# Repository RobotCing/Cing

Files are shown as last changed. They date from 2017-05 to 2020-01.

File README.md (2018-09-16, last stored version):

| [**Úvod**](README.md) |[**Cing**](README-cing-sk.md)  |[**GalejeNextGen**](README-GNG-sk.md)|[**Kontakt**](README-kontakt.md)|[**English version**](README-en.md)|[**Arduino portable**](https://drive.google.com/file/d/1-qsKpOY3mSJC7BOQW4kqXe5UFbl79BuX/view?usp=sharing)|
|:---:|:---:|:---:|:---:|:---:|:---:|
|[Attiny 85](README-Attiny85.md)|[Attiny 84](README-Attiny84.md)|[Atmega 8](README-Atmega8.md)|[Attiny 13](README-Attiny13.md)|[Atmega 328](README-Atmega328.md)|[Atmega 32u4](README-Atmega32u4.md)|

## Úvod:
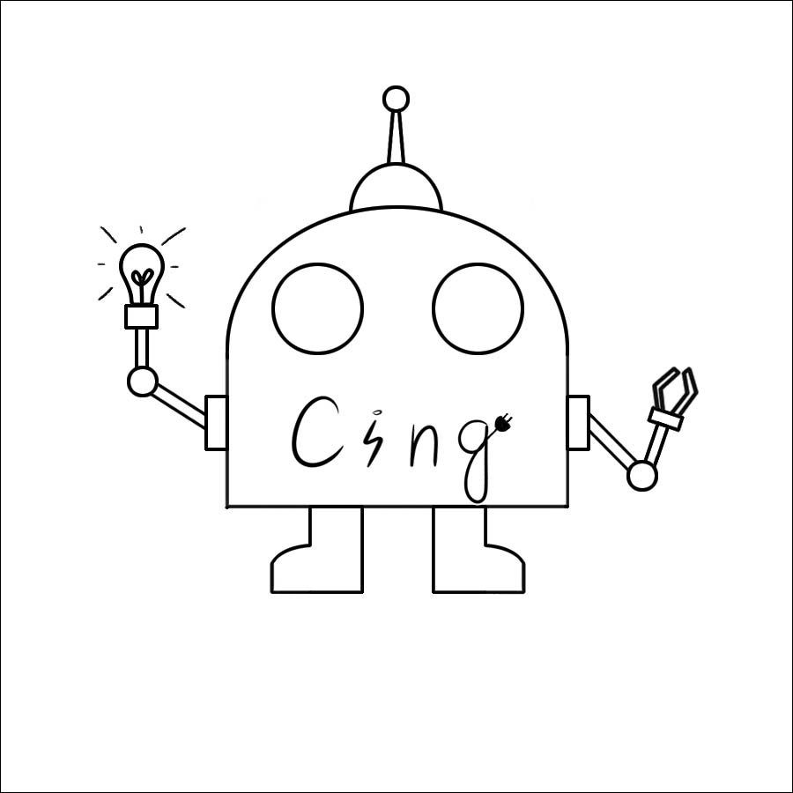
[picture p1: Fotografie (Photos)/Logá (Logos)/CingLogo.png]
Atmega 328 schematic


Každý pozná firmu [Lego](https://www.lego.com/en-us/). Vyrábajú najpopulárnejšie [Lego](https://www.lego.com/en-us/) stavebnice a sety. Vyrábajú <a href="https://www.lego.com/en-us/mindstorms">Lego NXT a Lego EV3</a> sety, ktoré sa jednoducho programujú a konštruujú, ale po naučení sa ich obrázkoveho jednoduchého programovacieho jazyka nemá užívaťeľ ďalšie možnosti ako programovať ich lego stavebnicu. Užívateľovi ostáva jediná možnosť - prejsť na inú platformu, napríklad [Arduino](https://www.arduino.cc/). 

[Arduino](https://www.arduino.cc/) je jedna z najlepších možností, nakoľko je lacnejšie ako akákoľvek iná platforma a taktiež je voľne dostupné. Ak sa užívateľ chce venovať [Arduinu](https://www.arduino.cc/), musí mať znalosti z elektroniky. Avšak tento fakt si mnoho ľudí uvedomí až keď si [Arduino](https://www.arduino.cc/) kúpi a vačšina z nich to vzdá. 

Preto sme vytvroli robota <a href="https://github.com/Galeje/Cing" target= "_blank">Cing</a> - je to multifunkčný a praktický robot pre všetky vekové kategórie od začiatočníkov až po expertov, nakoľko nie je potrebná žiadna znalosť z elektorniky či programovania. Pomocou nami vytvorených <a href="https://github.com/Galeje/Cing/tree/master/libraries" target= "_blank">knižníc</a>, ktoré umožňujü praktické a jednoduché využitie robota <a href="https://github.com/Galeje/Cing" target= "_blank">Cing</a> sa užívateľ naučí rýchlo, hravo a efektívne programovať.

Pre ešte ľahšie programovanie a učenie sa sme vytvorili príručky, ktoré obsahujú všetky programy a následne ich vysvetľujú. Aby užívateľ vedel, ako správne poskladať robota <a href="https://github.com/Galeje/Cing" target= "_blank">Cing</a>, použije opäť nami vytvorený manuál. Po naučení sa základných príkazov si môže vyskúšať cvičenia zo zbierky úloh na plátne s atrakciami.

Po zvládnutí základných aj pokročilých progamovacích príkazov môže používateľ použiť robota <a href="https://github.com/Galeje/Cing" target= "_blank">Cing</a> ako nástroj pre učenie sa elektroniky, nakoľko sa jednoducho dostane k schémam aj príručke, ako ho programovať bez použitia <a href="https://github.com/Galeje/Cing/tree/master/libraries" target= "_blank">knižníc</a>. To znamená, že užívateľ si môže vybrať, ako chce programovať <a href="https://github.com/Galeje/" target= "_blank">Cing-a</a>.

<!---Každú pozná firmu [Lego](https://www.lego.com/en-us/). Vyrábajú najpopulárnejšie [Lego](https://www.lego.com/en-us/) stavebnice a sety. Vyrábajú <a href="https://www.lego.com/en-us/mindstorms">Lego NXT and Lego EV3</a>sety ktoré sa jednoducho programujú a konštruujú, ale po naučení sa ich obrázkoveho jednoduchého programovacieho jazyka nemá užívaťeľ ďalšie možnosti ako programovat ich lego stavebnicu. Užívateľovi ostáva jediná možnosť - Prejisť na inú platformu napríklad [Arduino](https://www.arduino.cc/). [Arduino](https://www.arduino.cc/) je super možnosť nakoľko je Open Source, je lacnejšie, ale užívaťel musí rozumieť elektronike. Tento fakt si mnoho ľudí uvedomí až keď si [Arduino](https://www.arduino.cc/) kúpi a vačšina ľudí to vzdá.
<a href="https://github.com/Galeje/Cing" target= "_blank">Cing</a> rieši tento problém <a href="https://github.com/Galeje/Cing/tree/master/libraries" target= "_blank">knižnicami</a> ktoré umožňujú jednoduché programovanie <a href="https://github.com/Galeje/Cing" target= "_blank">Cing-a</a> v C programovaciom jazyku bez nutnosťi znalosti elektroniky. Taktiež sme vytvorili <a href="https://github.com/Galeje/Cing/blob/master/CINGtlac.pdf">príručky</a>, ktoré naučia užívateľa programovat <a href="https://github.com/Galeje/Cing" target= "_blank">Cing-a</a>.Po naučení sa základných aj pokročilých progamovacích príkazov môže používateľ použiť robota <a href="https://github.com/Galeje/Cing" target= "_blank">Cing</a> ako nástroj pre učenie sa elektroniky, nakoľko sa jednoducho dostane k schémam aj príručke ako ho programovať bez použitia <a href="https://github.com/Galeje/Cing/tree/master/libraries" target= "_blank">knižníc</a>. To znamená, že užívateľ si môže vybrať ako chce programovať <a href="https://github.com/Galeje/Cing" target= "_blank">Cing-a</a>.--->

## Package link
`https://raw.githubusercontent.com/RobotCing/Cing/master/Software/Packages/index/package_RobotCing_index.json`

Projekt používa <a href="https://github.com/MCUdude/MicroCore">MicroCore</a> a <a href="https://github.com/damellis">Damellis</a> <a href="https://github.com/damellis/attiny">ATtiny core</a>.

## Podporte nás:




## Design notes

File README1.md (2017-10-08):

|||||||
|---|---|---|---|---|---|
| [**Úvod**](README-sk.md) | [**Cing**](README-cing-sk.md)  |[**GalejeNextGen**](README-GNG-sk.md) |[**Kontakt**](README-kontakt.md)|[**English version**](README.md)|[**Arduino portable**](https://drive.google.com/file/d/0B4RmGq_2LqvyWHNMNzY1T0phVmM/view?usp=sharing)|

## Úvod:
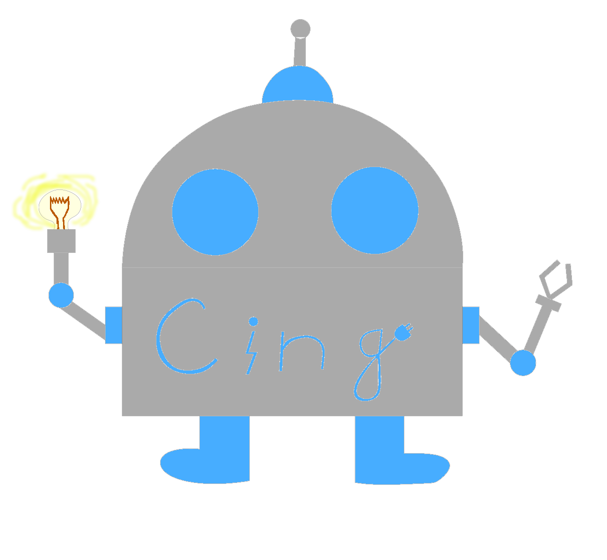
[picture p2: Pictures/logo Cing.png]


Každý pozná firmu [Lego](https://www.lego.com/en-us/). Vyrábajú najpopulárnejšie [Lego](https://www.lego.com/en-us/) stavebnice a sety. Vyrábajú <a href="https://www.lego.com/en-us/mindstorms">Lego NXT a Lego EV3</a> sety, ktoré sa jednoducho programujú a konštruujú, ale po naučení sa ich obrázkoveho jednoduchého programovacieho jazyka nemá užívaťeľ ďalšie možnosti ako programovať ich lego stavebnicu. Užívateľovi ostáva jediná možnosť - prejsť na inú platformu, napríklad [Arduino](https://www.arduino.cc/). 

[Arduino](https://www.arduino.cc/) je jedna z najlepších možností, nakoľko je lacnejšie ako akákoľvek iná platforma a taktiež je voľne dostupné. Ak sa užívateľ chce venovať [Arduinu](https://www.arduino.cc/), musí mať znalosti z elektroniky. Avšak tento fakt si mnoho ľudí uvedomí až keď si [Arduino](https://www.arduino.cc/) kúpi a vačšina z nich to vzdá. 

Preto sme vytvroli robota <a href="https://github.com/Galeje/Cing" target= "_blank">Cing</a> - je to multifunkčný a praktický robot pre všetky vekové kategórie od začiatočníkov až po expertov, nakoľko nie je potrebná žiadna znalosť z elektorniky či programovania. Pomocou nami vytvorených <a href="https://github.com/Galeje/Cing/tree/master/libraries" target= "_blank">knižníc</a>, ktoré umožňujü praktické a jednoduché využitie robota <a href="https://github.com/Galeje/Cing" target= "_blank">Cing</a> sa užívateľ naučí rýchlo, hravo a efektívne programovať.

Pre ešte ľahšie programovanie a učenie sa sme vytvorili príručky, ktoré obsahujú všetky programy a následne ich vysvetľujú. Aby užívateľ vedel, ako správne poskladať robota <a href="https://github.com/Galeje/Cing" target= "_blank">Cing</a>, použije opäť nami vytvorený manuál. Po naučení sa základných príkazov si môže vyskúšať cvičenia zo zbierky úloh na plátne s atrakciami.

Po zvládnutí základných aj pokročilých progamovacích príkazov môže používateľ použiť robota <a href="https://github.com/Galeje/Cing" target= "_blank">Cing</a> ako nástroj pre učenie sa elektroniky, nakoľko sa jednoducho dostane k schémam aj príručke, ako ho programovať bez použitia <a href="https://github.com/Galeje/Cing/tree/master/libraries" target= "_blank">knižníc</a>. To znamená, že užívateľ si môže vybrať, ako chce programovať <a href="https://github.com/Galeje/" target= "_blank">Cing-a</a>.

<!---Každú pozná firmu [Lego](https://www.lego.com/en-us/). Vyrábajú najpopulárnejšie [Lego](https://www.lego.com/en-us/) stavebnice a sety. Vyrábajú <a href="https://www.lego.com/en-us/mindstorms">Lego NXT and Lego EV3</a>sety ktoré sa jednoducho programujú a konštruujú, ale po naučení sa ich obrázkoveho jednoduchého programovacieho jazyka nemá užívaťeľ ďalšie možnosti ako programovat ich lego stavebnicu. Užívateľovi ostáva jediná možnosť - Prejisť na inú platformu napríklad [Arduino](https://www.arduino.cc/). [Arduino](https://www.arduino.cc/) je super možnosť nakoľko je Open Source, je lacnejšie, ale užívaťel musí rozumieť elektronike. Tento fakt si mnoho ľudí uvedomí až keď si [Arduino](https://www.arduino.cc/) kúpi a vačšina ľudí to vzdá.
<a href="https://github.com/Galeje/Cing" target= "_blank">Cing</a> rieši tento problém <a href="https://github.com/Galeje/Cing/tree/master/libraries" target= "_blank">knižnicami</a> ktoré umožňujú jednoduché programovanie <a href="https://github.com/Galeje/Cing" target= "_blank">Cing-a</a> v C programovaciom jazyku bez nutnosťi znalosti elektroniky. Taktiež sme vytvorili <a href="https://github.com/Galeje/Cing/blob/master/CINGtlac.pdf">príručky</a>, ktoré naučia užívateľa programovat <a href="https://github.com/Galeje/Cing" target= "_blank">Cing-a</a>.Po naučení sa základných aj pokročilých progamovacích príkazov môže používateľ použiť robota <a href="https://github.com/Galeje/Cing" target= "_blank">Cing</a> ako nástroj pre učenie sa elektroniky, nakoľko sa jednoducho dostane k schémam aj príručke ako ho programovať bez použitia <a href="https://github.com/Galeje/Cing/tree/master/libraries" target= "_blank">knižníc</a>. To znamená, že užívateľ si môže vybrať ako chce programovať <a href="https://github.com/Galeje/Cing" target= "_blank">Cing-a</a>.--->
## Prehľad:
Cing model
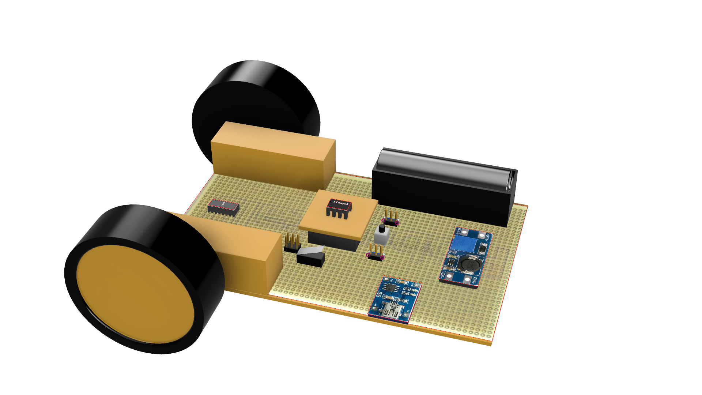
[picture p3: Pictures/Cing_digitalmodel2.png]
Cing model


<a href="https://goo.gl/kuoLt5" target="_blank">Stiahni Arduino Portable</a>

## Komponenty:
 - ### Procesory:
   - Attiny13 procesor
   - Attiny85 procesor
   - Attiny84 procesor
   - Atmega8 procesor
   - Atmega328 procesor
   - Atmega32u4 procesor(vo vývoji)
 - ### Senzory(Vstupy):
   - DS18B20 temperature sensor
   - Shine sensor
   - 2 x light sensor
   - ultasonic sensor
 - ### Výstupy:
   - L293D
   - Display128x32(vo vývoji)
 - ### Robot parts:
   - Základny robot
   - ICSP programmer
   - Li-Ion 18650 baterka
   - ICSP ASP programátor
 - ### Potrebné nástroje:
   - Počítač
   - Čierna páska(izolepa) pre vytvorenie čiar
   - Povrch pre čiaru
   - Prekážky

## Schémy:
### Schéma Atmega328 procesor
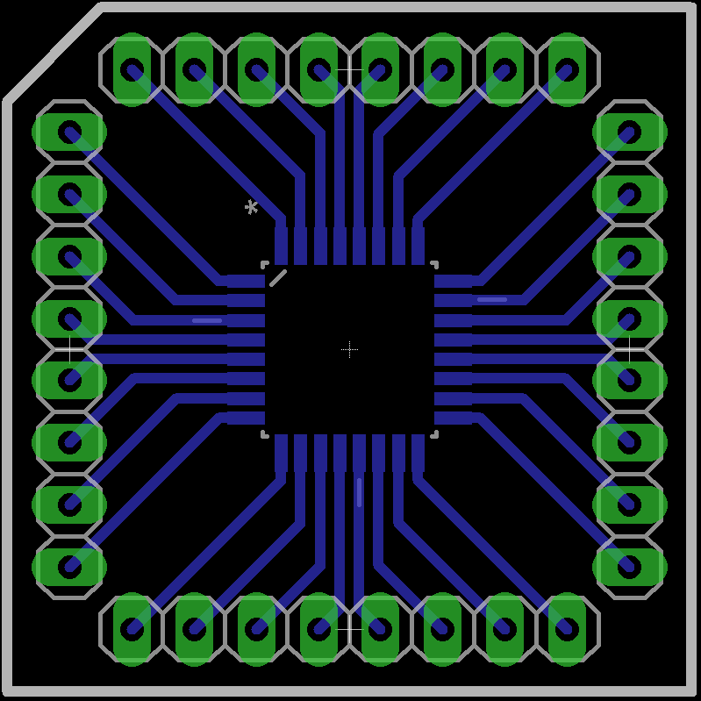
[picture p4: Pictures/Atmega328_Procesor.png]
Atmega 328 schematic

### Schéma Atmega8 procesor
<a href="https://github.com/Galeje/Cing/tree/master/Schematic">Atmega 8 schematic</a>
### Schéma Attiny85 procesor
<a href="https://github.com/Galeje/Cing/tree/master/Schematic">Attiny 85 schematic</a>
### Schéma Cing robot
<a href="https://github.com/Galeje/Cing/tree/master/Schematic">Cing schematic</a>

## Fotky:
### Poskladaný robot:
Cing assembled

## Podporte nás:




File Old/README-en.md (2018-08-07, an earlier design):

| [**Introduction**](README-en.md) |[**Cing**](README-cing.md)  |[**GalejeNextGen**](README-GNG.md)|[**Contact**](README-contact.md)|[**Slovak version**](README.md)|[**Arduino portable**](https://goo.gl/Sfmrn4)|
|:---:|:---:|:---:|:---:|:---:|:---:|
|[Attiny 85](README-Attiny85-en.md)|[Attiny 84](README-Attiny84-en.md)|[Atmega 8](README-Atmega8-en.md)|[Attiny 13](README-Attiny13-en.md)|[Atmega 328](README-Atmega328-en.md)|[Atmega 32u4](README-Atmega32u4-en.md)|

## Introduction:


Everybody knows [Lego](https://www.lego.com/en-us/) as an campany. They are making most popular [Lego](https://www.lego.com/en-us/) sets and robots ever. They have <a href="https://www.lego.com/en-us/mindstorms">Lego NXT and Lego EV3</a> robot sets which are easy to program and build, but after you have learned how to program them with [Lego](https://www.lego.com/en-us/) software there isn't any other programing language. So  if you want to learn some other language you have to get something else for example [Arduino](https://www.arduino.cc/).

[Arduino](https://www.arduino.cc/) is great platform because it is an open source, cheaper than [Lego](https://www.lego.com/en-us/) and you aren't that limited. But when you get arduino you will sooner or later realise, that you have to know how electronics works. And that's the point where most of people will give up.

<a href="https://github.com/Galeje/Cing" target= "_blank">Cing</a> solves this problem because it has a <a href="https://github.com/Galeje/ing/tree/master/libraries" target= "_blank">libraries</a> which allow users to easely program <a href="https://github.com/Galeje/Cing" target= "_blank">Cing</a> in C language without electronic knowleadge. We also created pdf <a href="https://github.com/Galeje/Cing/blob/master/CINGtlac.pdf">guide</a>  which teaches you the basics of programing <a href="https://github.com/Galeje/Cing" target= "_blank">Cing</a> robot. 

After learning the basics of programing with <a href="https://github.com/Galeje/ing/tree/master/libraries" target= "_blank">libraries</a> they can use <a href="https://github.com/Galeje/Cing" target= "_blank">Cing</a> robot as learning tool for electronics, because it has an open source design. That mean that they can program it with [Arduino](https://www.arduino.cc/) language or AVR language.

<a href="https://github.com/Galeje/Cing/blob/master/Fotografie%20(Photos)/Log%C3%A1%20(Logos)/CingLogo.png">Atmega 328 schematic</a>

Project uses <a href="https://github.com/MCUdude/MicroCore">MicroCore</a> and <a href="https://github.com/damellis">Damellis</a> <a href="https://github.com/damellis/attiny">ATtiny core</a>.
## Support




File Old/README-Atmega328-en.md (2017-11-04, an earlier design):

| [**Introduction**](README-en.md) |[**Cing**](README-cing.md)  |[**GalejeNextGen**](README-GNG.md)|[**Contact**](README-contact.md)|[**Slovak version**](README.md)|[**Arduino portable**](https://goo.gl/Sfmrn4)|
|:---:|:---:|:---:|:---:|:---:|:---:|
|[Attiny 85](README-Attiny85-en.md)|[Attiny 84](README-Attiny84-en.md)|[Atmega 8](README-Atmega8-en.md)|[Attiny 13](README-Attiny13-en.md)|[Atmega 328](README-Atmega328-en.md)|[Atmega 32u4](README-Atmega32u4-en.md)|

# 5.part - Atmega328
In progress

## Components:

### Procesor:


### ICSP AVR Programmer:


### Li-Ion Battery:


### Sensors:




### Abilities of this model:
 - Movement forward
 - Movement backward
 - Line followig
 - Light measuring
 - Distance measuring
 - Temperature measuring
 - Potenciometer measuring
 - Buzzing
 - Buzzing measuring

## Support us:




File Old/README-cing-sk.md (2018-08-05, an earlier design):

| [**Úvod**](README.md) |[**Cing**](README-cing-sk.md)  |[**GalejeNextGen**](README-GNG-sk.md)|[**Kontakt**](README-kontakt.md)|[**English version**](README-en.md)|[**Arduino portable**](https://drive.google.com/file/d/1-qsKpOY3mSJC7BOQW4kqXe5UFbl79BuX/view?usp=sharing)|
|:---:|:---:|:---:|:---:|:---:|:---:|
|[Attiny 85](README-Attiny85.md)|[Attiny 84](README-Attiny84.md)|[Atmega 8](README-Atmega8.md)|[Attiny 13](README-Attiny13.md)|[Atmega 328](README-Atmega328.md)|[Atmega 32u4](README-Atmega32u4.md)|

# Cing
  Robot Cing je praktický a multifunkčný, nakoľko má jeden základný model, na ktorý je možné pripájať komponenty, moduly a procesory zo všetkých časí robota Cing. 

## Výhody robota Cing:
-	Nepotrebná znalosť informatiky
-	Voľne prístupné diely
-	Vhodný pre všetky vekové kategórie
-	Pre začiatočníkov, ale aj pokročilých
-	Zábavná výučba vďaka edukačnému plátnu a cvičebniciam
-	Cenovo výhodný robot

## Cenová kalkulácia:

| Komponenty | Cena | Počet | Spolu  |
|---|:---:|:-----:|:---:|
| 18650 Baterka | 9,00 € | 1 | 9,00 € |
| 18650 Držiak Baterky | 1,60 € | 1 | 1,60 € |
| ICSP Konektor | 0,10 € | 1 | 0,10 € |
| TP4056 | 0,50 € | 1 | 0,50 € |
| Svetelný Senzor | 1,00 € | 2 | 2,00 € |
| Ultrasonický Senzor | 1,00 € | 1 | 1,00 € |
| DS18b20 | 1,00 € | 1 | 1,00 € |
| Senzor osvetlenia | 0,10 € | 1 | 0,10 € |
| ICSP Programátor | 1,80 € | 1 | 1,80 € |
| Dodatočne elektornické súčiastky | 5,00 € | 1 | 5,00 € |
| Motory | 1,20 € | 2 | 2,40 € |
| L293 | 0,50 € | 1 | 0,50 € |

| Procesory | Cena | Počet | Spolu  |
|---|:---:|:-----:|:---:|
| Attiny85 | 1,00 € | 1 | 1,00 € |
| Attiny84 | 2,10 € | 1 | 2,10 € |
| Atmega8 | 0,80 € | 1 | 0,80 € |
| Attiny13 | 0,50 € | 1 | 0,50 € |
| Atmega328 | 1,00 € | 1 | 1,00 € |
| Atmega32u4 | 4,00 € | 1 | 4,00 € |

| Plošné spoje | Cena | Počet | Spolu  |
|---|:---:|:-----:|:---:|
| Cing hlavný plošný spoj | 9,00 € | 1 | 9,00 € |
| Attiny85 PCB | 1,00 € | 1 | 1,00 € |
| Attiny84 PCB | 1,00 € | 1 | 1,00 € |
| Atmega8 PCB | 1,00 € | 1 | 1,00 € |
| Attiny13 PCB | 1,00 € | 1 | 1,00 € |
| Atmega328 PCB | 1,00 € | 1 | 1,00 € |
| Atmega32u4 PCB | 1,00 € | 1 | 1,00 € |

### Robot Cing

|  JEDNOTLIVÉ ČASTI ROBOTA Cing | Cena  | Počet | Spolu |
|---|:---:|:-----:|:---:|
| Cing Attiny85 | 36,00 € | 1 | 36,00 € |
| Cing Attiny84 |  3,10 € | 1 |  3,10 € |
| Cing Atmega8 |  1,80 € | 1 |  1,80 € |
| Cing Attiny13 |  1,50 € | 1 |  1,50 € |
| Cing Atmega328 |  2,00 € | 1 |  2,00 € |
| Cing Atmega32u4 |  5,00 € | 1 |  5,00 € |

|  SADY ROBOTA Cing | Cena  | Počet | Spolu |
|---|:---:|:-----:|:---:|
| Cing Attiny85 | 36,00 € | 1 | 36,00 € |
| Cing Attiny85 + Attiny84 | 39,10 € | 1 | 39,10 € |
| Cing Attiny85 + Attiny85 + Atmega8 | 40,90 € | 1 | 40,90 € |
| Cing Attiny85 + Attiny85 + Atmega8 + Attiny13 | 42,40 € | 1 | 42,40 € |
| Cing Attiny85 + Attiny85 + Atmega8 + Atmega328 | 44,40 € | 1 | 44,40 € |
| Cing Attiny85 + Attiny85 + Atmega8 + Atmega328 + Atmega32u4 | 49,40 € | 1 | 49,40 € |

## Podporte nás:




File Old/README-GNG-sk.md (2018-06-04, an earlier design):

| [**Úvod**](README.md) |[**Cing**](README-cing-sk.md)  |[**GalejeNextGen**](README-GNG-sk.md)|[**Kontakt**](README-kontakt.md)|[**English version**](README-en.md)|[**Arduino portable**](https://drive.google.com/file/d/1-qsKpOY3mSJC7BOQW4kqXe5UFbl79BuX/view?usp=sharing)|
|:---:|:---:|:---:|:---:|:---:|:---:|
|[Attiny 85](README-Attiny85.md)|[Attiny 84](README-Attiny84.md)|[Atmega 8](README-Atmega8.md)|[Attiny 13](README-Attiny13.md)|[Atmega 328](README-Atmega328.md)|[Atmega 32u4](README-Atmega32u4.md)|

# GalejeNextGen
  Sme tím študentov z osemročného gymnázia na Alejovej ulici v Košiciach. Počet aktívnych členov nášho tímu sa mení v závislosti od súťaží. Už niekoľko generácií úspešne reprezentujeme našu školou na rôznych súťažiach z robotiky, informatiky či programovania po celom svete.
  
  Na Festivale vedy a techniky vystupujeme ako dvojčlenný tím v zložení Stanislav Jochman a Veronika Nemjová. Venujeme sa projektu Robot Cing, o ktorom sa viac dozviete na tejto stránke.

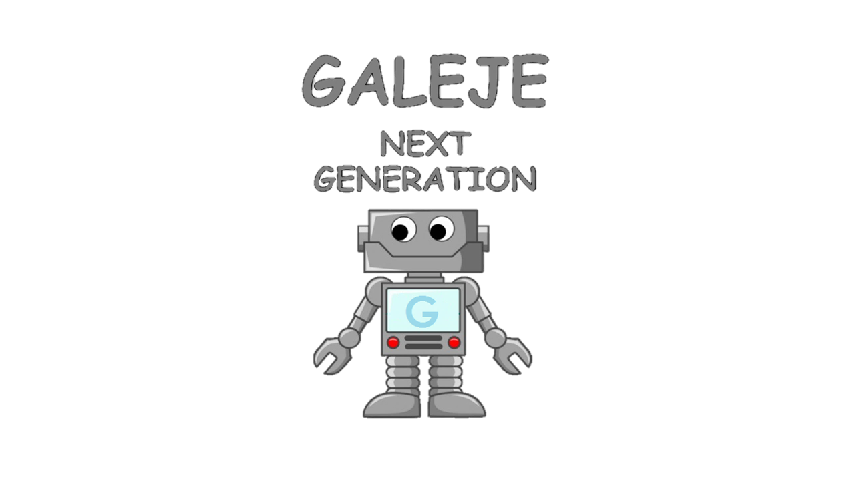
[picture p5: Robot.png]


## Podporte nás:




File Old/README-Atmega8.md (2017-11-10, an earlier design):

| [**Úvod**](README.md) |[**Cing**](README-cing-sk.md)  |[**GalejeNextGen**](README-GNG-sk.md)|[**Kontakt**](README-kontakt.md)|[**English version**](README-en.md)|[**Arduino portable**](https://goo.gl/Sfmrn4)|
|:---:|:---:|:---:|:---:|:---:|:---:|
|[Attiny 85](README-Attiny85.md)|[Attiny 84](README-Attiny84.md)|[Atmega 8](README-Atmega8.md)|[Attiny 13](README-Attiny13.md)|[Atmega 328](README-Atmega328.md)|[Atmega 32u4](README-Atmega32u4.md)|

# 3.časť - Policajt
 Tretia časť zo séria robotov robota Cing má nové komponenty. 
 
 Séria obsahuje:
-	Procesor Atmega8

-	LEDky

-	Inštalačné CD

-	Príručku pre vysvetlenie programov

-	Manuál na správne zapojenie senzorov a inštaláciu programu

-	Cvičebnicu pre zábavnejšie učenie sa a posilňovanie vedomostí

-	Edukačné plátno

### Sumár:

Túto časť sme pomenovali podľa jej funkcií.

Názov:		Robot Cing – Policajt

Procesor:	Atmega8

### Cena:

1,80€ (v cene sú zahrnuté všetky časti, ktoré obsahuje 3.časť)
		
40,90€ (cena za prvú, druhú a tretiu časť spolu)

### Cenová kalkulácia:

## Funkcie tohto modelu
 - Pohyb dopredu
 - Pohyb dozadu
 - Sledovanie čiary
 - Meranie hodnoty svetla
 - Meranie zmeny osvetlenia
 - Meranie vzdialenosti
 - Meranie zmeny teploty
 - Meranie hodnoty potenciometra
 - Meranie hodnoty tlačidla
 - Vydávať zvuk
 - Svietiť všetkými farbami
 
### Knižky:

### Plátno:

## Podporte nás:




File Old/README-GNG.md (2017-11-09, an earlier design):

| [**Introduction**](README-en.md) |[**Cing**](README-cing.md)  |[**GalejeNextGen**](README-GNG.md)|[**Contact**](README-contact.md)|[**Slovak version**](README.md)|[**Arduino portable**](https://goo.gl/Sfmrn4)|
|:---:|:---:|:---:|:---:|:---:|:---:|
|[Attiny 85](README-Attiny85-en.md)|[Attiny 84](README-Attiny84-en.md)|[Atmega 8](README-Atmega8-en.md)|[Attiny 13](README-Attiny13-en.md)|[Atmega 328](README-Atmega328-en.md)|[Atmega 32u4](README-Atmega32u4-en.md)|

# GalejeNextGen
We are team of students from eight-year high school at Alejova street in Košice. Count of sctive members of our team is changing in between the competitions. We are representing our school in the robotic, informatic and programming competitions in the world succesfully for several generations. 

At Festival of science and technics we are two member team . The members are Stanley Jochman and Veronika Nemjová. We are working on the project of the Robot Cing. For more information, look at our page.



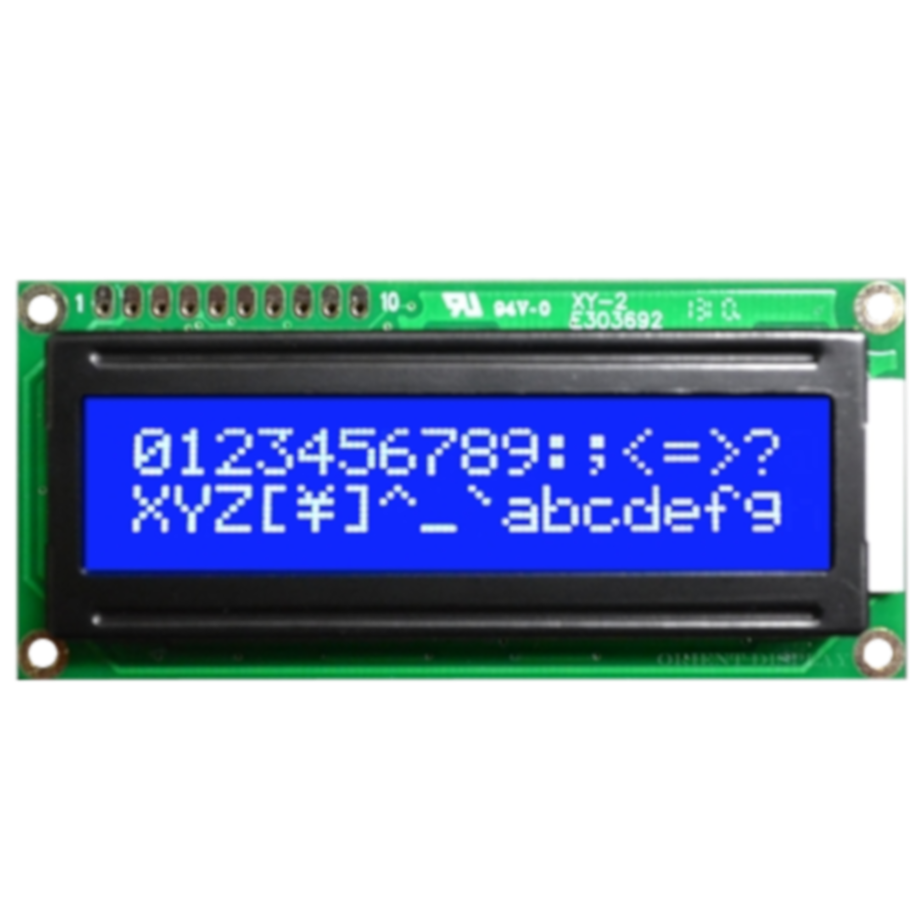
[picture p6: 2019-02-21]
Software/Cing Checker/img/16x2.png

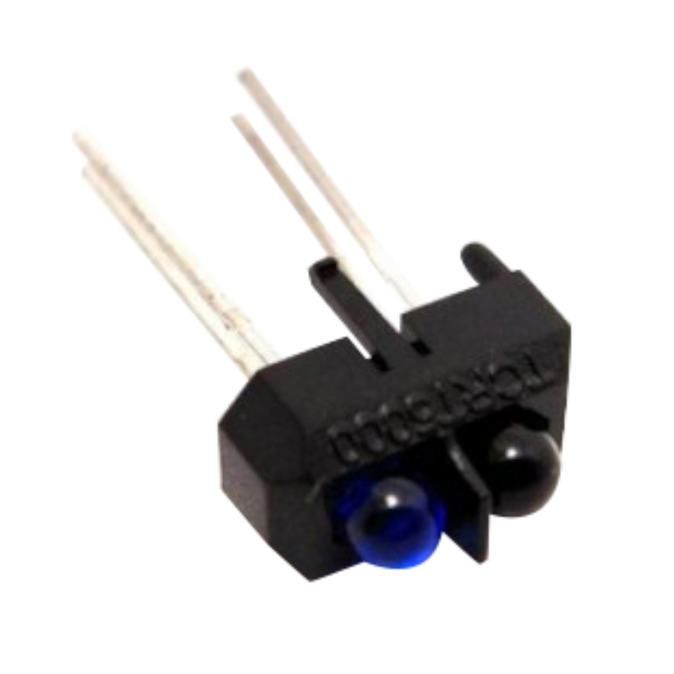
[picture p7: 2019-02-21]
Software/Cing Checker/img/lightsensor.png

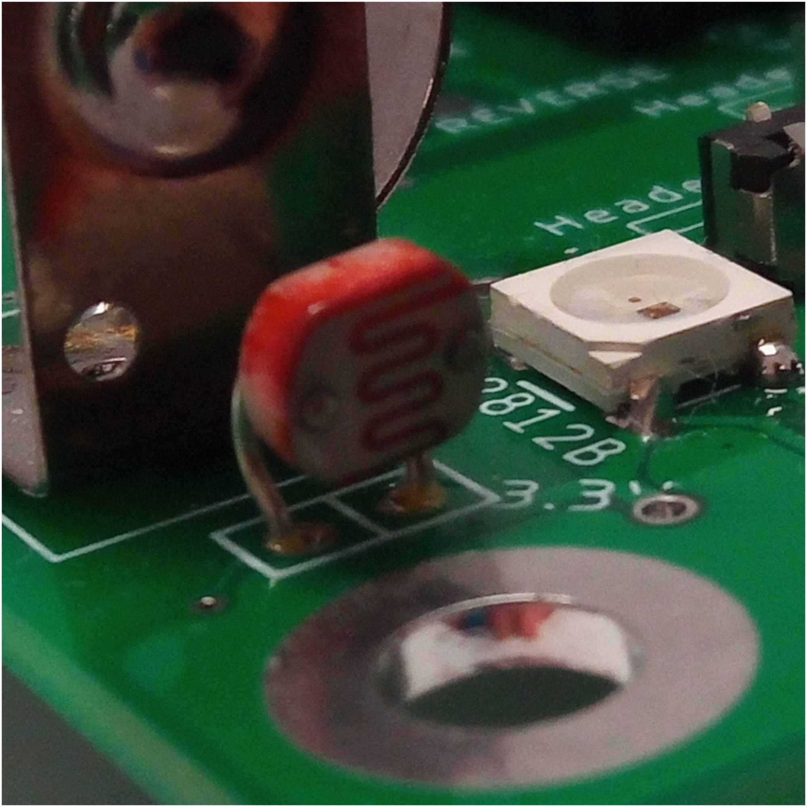
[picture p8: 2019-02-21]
Software/Cing Checker/img/shinearray.png

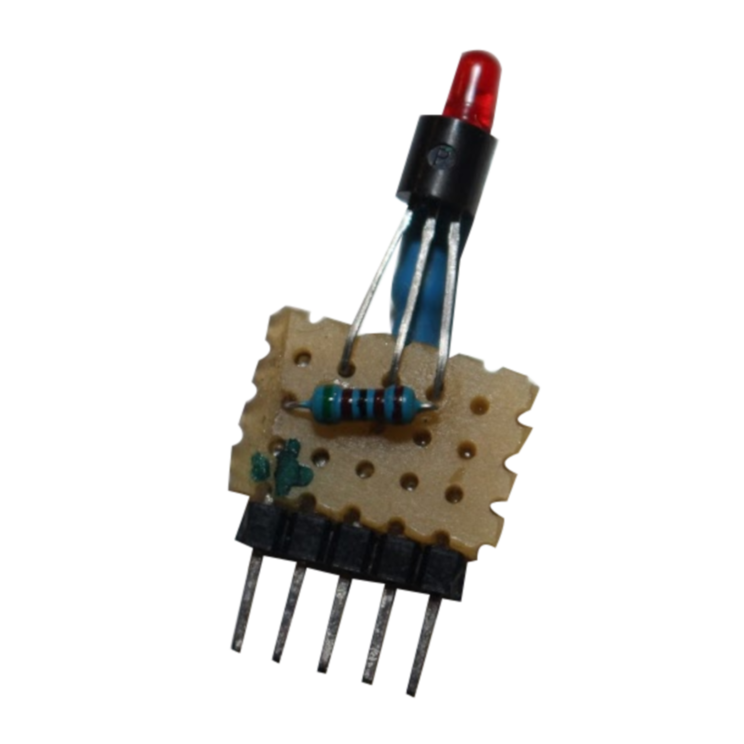
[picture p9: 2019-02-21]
Software/Cing Checker/img/TemperatureSensor.png

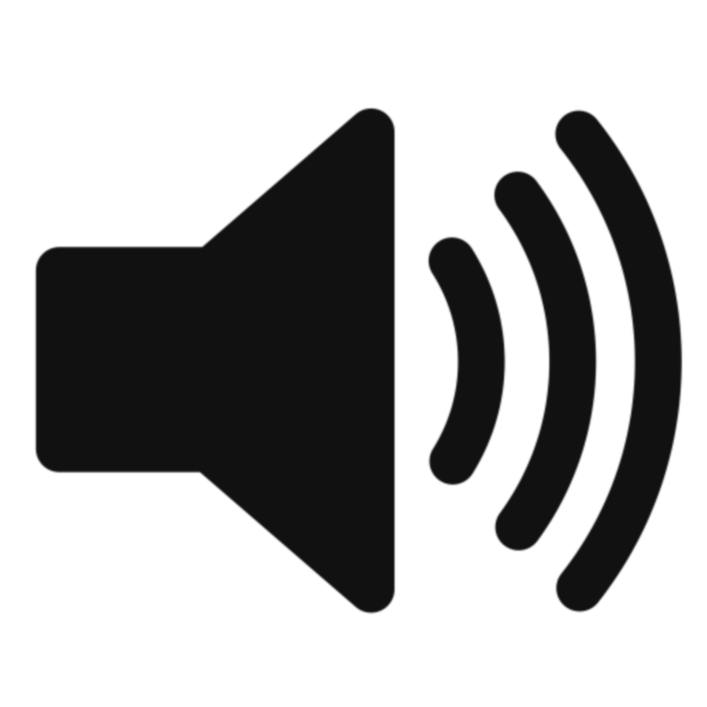
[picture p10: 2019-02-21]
Software/Cing Checker/img/speaker.png

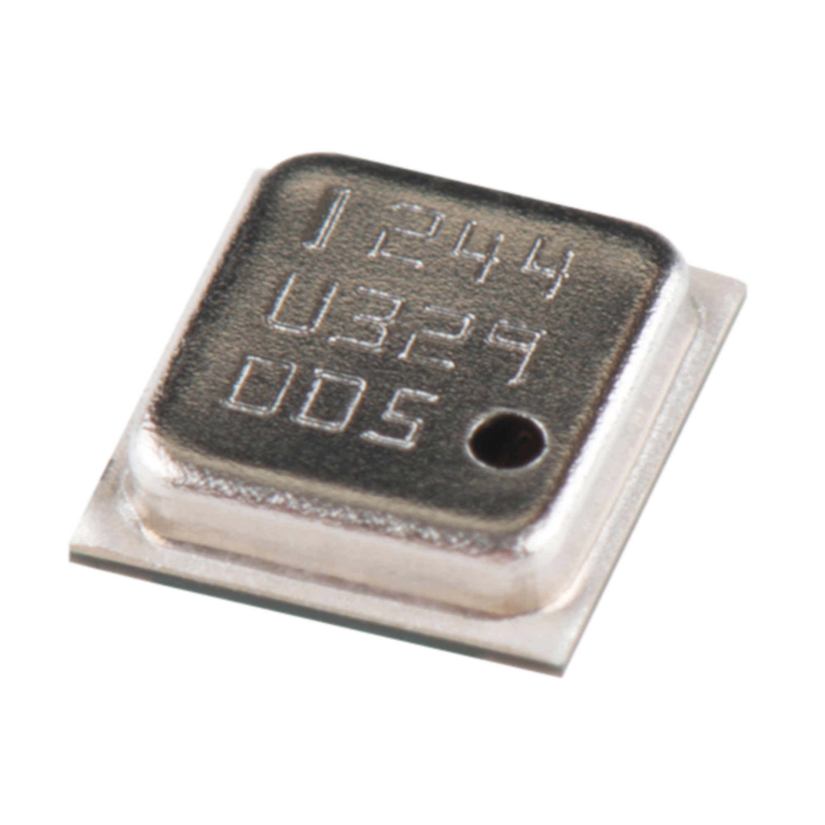
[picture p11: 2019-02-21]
Software/Cing Checker/img/bmp180.png

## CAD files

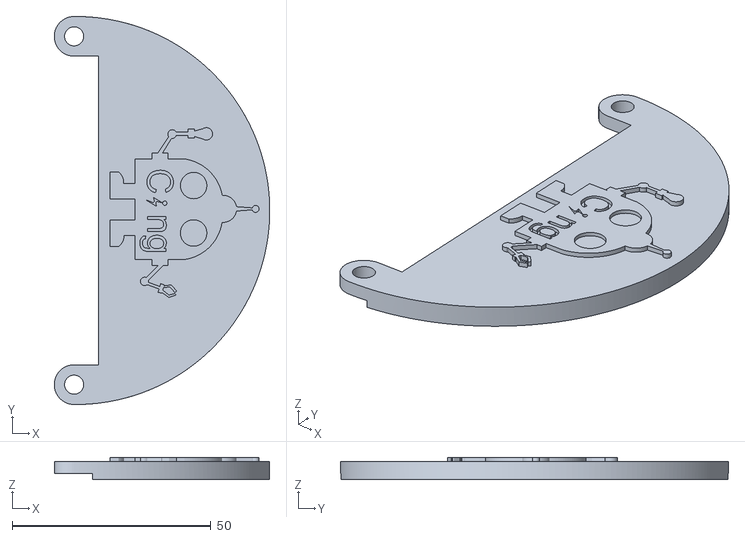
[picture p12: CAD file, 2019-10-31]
Hardware/3D parts/front decoration.stl
54.2 x 97.7 x 5.60

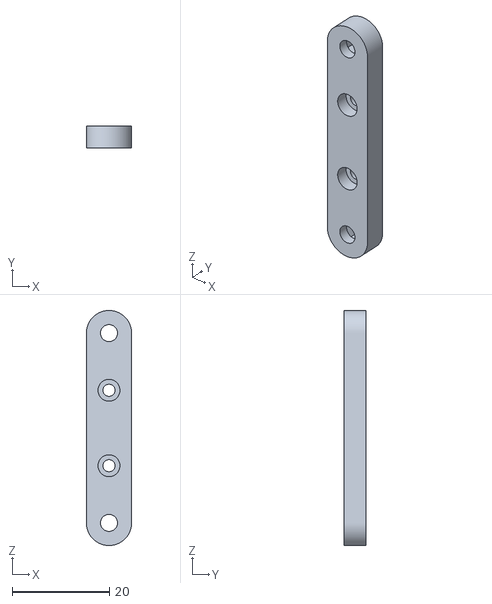
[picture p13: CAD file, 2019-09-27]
Hardware/3D parts/Cing ball adapter.stl
9.30 x 4.50 x 48.3

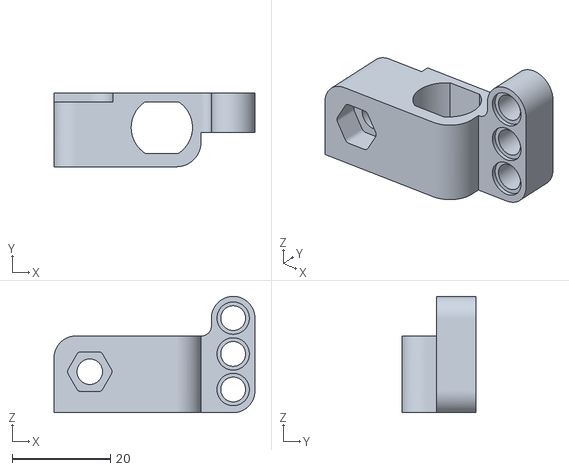
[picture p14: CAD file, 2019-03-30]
Hardware/3D parts/MotorHolderRight.stl
41.0 x 15.0 x 23.8

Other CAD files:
Hardware/3D parts/MotorHolderLeft.stl

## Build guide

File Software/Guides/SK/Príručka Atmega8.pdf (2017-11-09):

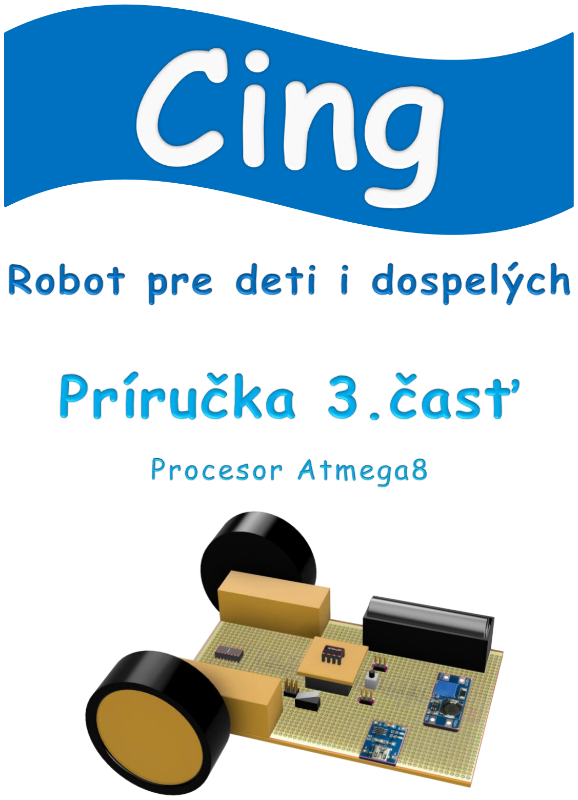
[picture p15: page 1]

;

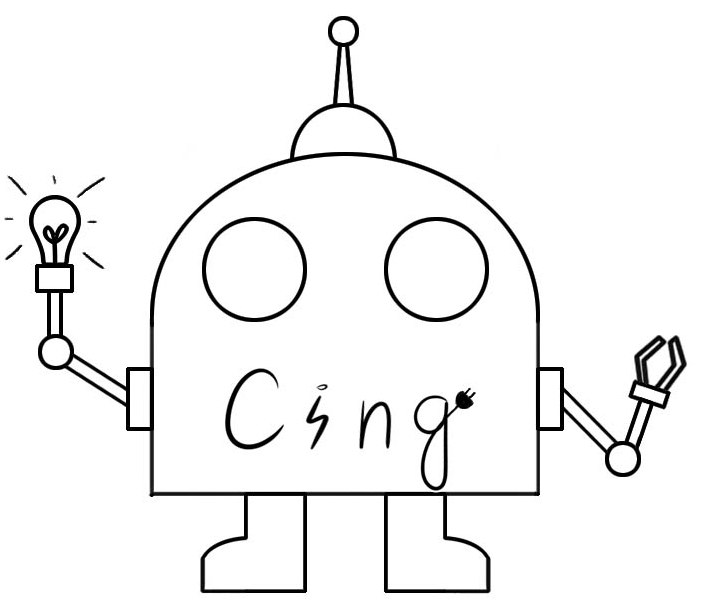
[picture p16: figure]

2

## ÚVOD

V tejto krátkej príručke sa zoznámite s ďalšími príkazmi a komponentmi pre robota Cing a naučíte sa opäť nové príkazy a funkcie zábavnou formou. Pribudli nám aj nové senzory, a tiež sa zmenil typ mikrokontroléra. To znamená, že nebude podporovať analógové vstupy komponentov. Viac už sa dozviete v príručke.

3

## OBSAH

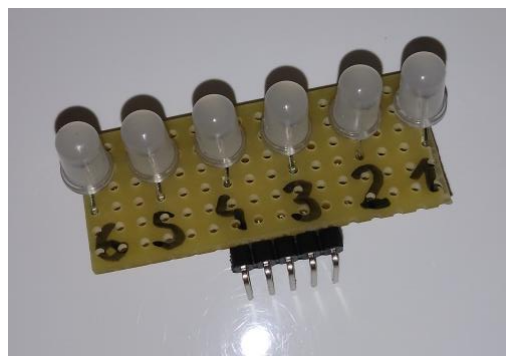
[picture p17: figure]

4

## 1. ZOZNÁMME SA S NOVINKAMI

Farebné LEDky

## 2. PREKÁŽKY

V tejto | kapitole | si | znova | ukážeme | prácu
s ultrasonickým senzorom a pridáme mu na zaujímavé programové funkcie.

Budeme potrebovať:

- Robota Cing
- Ultrasonický senzor
- Bzučiak
- ICSP AVR programátor

Stratégia:

Robot Cing pôjde dopredu na oboch motoroch. Ak zaznamená prekážku vo vzdialenosti menej ako 20 cm, zastaví sa a začne húkať.

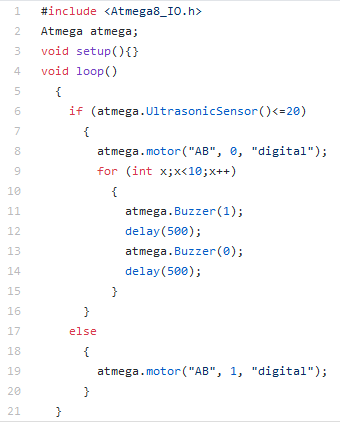
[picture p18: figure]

5

Program:

Vysvetlenie programu:

V prvom a druhom riadku programu sú príkazy určené pre programovacie prostredie, ktoré implementujú knižnicu <Atmega8_IO.h>.

Príkazy vo void loop(){} v svorkových zátvorkách:{} bežia v nekonečnom procese a opakujú sa.

V šiestom riadku programu zadávame podmienku pre
ultrasonický | senzor.
Ak je jeho hodnota menšia alebo rovná 20, vykoná sa proces v zátvorkách → v deviatom riadku vytvárame

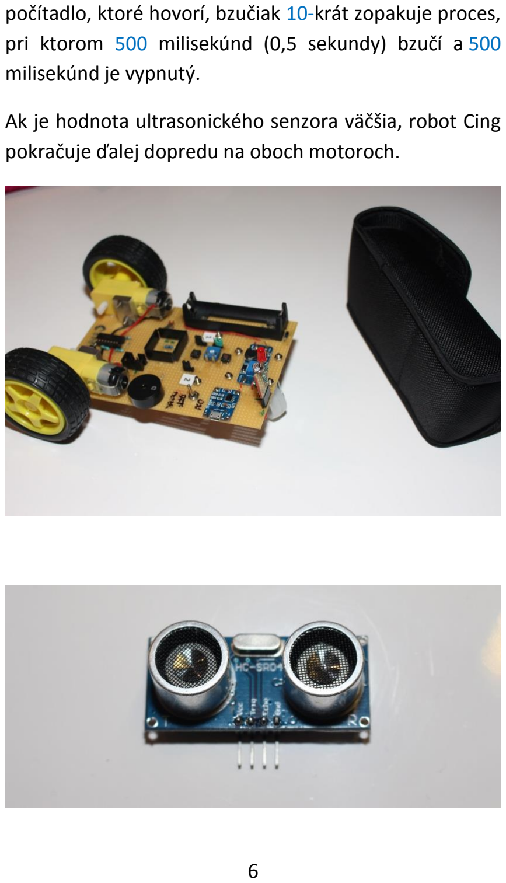
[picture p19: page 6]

6

počítadlo, ktoré hovorí, bzučiak 10-krát zopakuje proces, pri ktorom 500 milisekúnd (0,5 sekundy) bzučí a 500 milisekúnd je vypnutý.

Ak je hodnota ultrasonického senzora väčšia, robot Cing pokračuje ďalej dopredu na oboch motoroch.

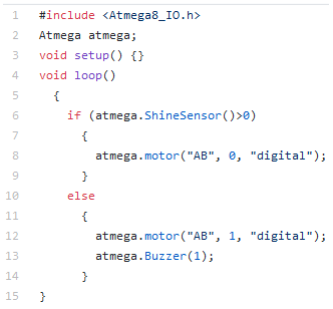
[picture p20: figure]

7

## 3. OSVETLENIE

V tejto | kapitole | si | znova | ukážeme | prácu
s ultrasonickým senzorom a pridáme mu na zaujímavé programové funkcie.

Budeme potrebovať:

- Robota Cing
- Senzor osvetlenia
- Bzučiak
- ICSP AVR programátor

Stratégia:

Robot Cing pôjde dopredu na oboch motoroch. Ak osvetlíme senzor osvetlenia, robot Cing sa zastaví a začne húkať.

Program:

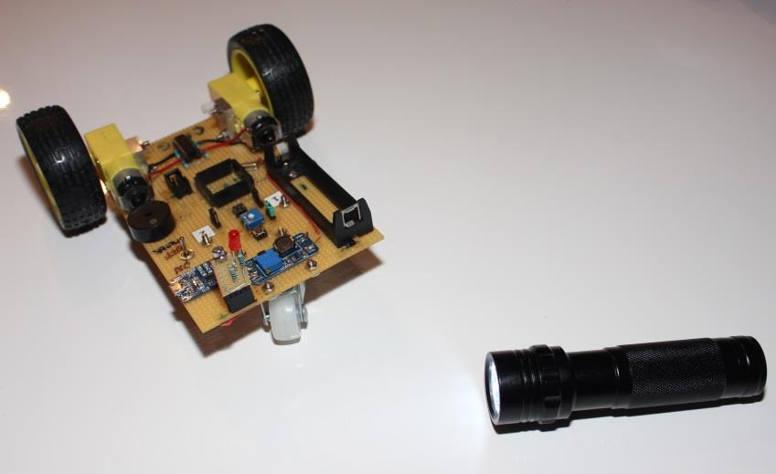
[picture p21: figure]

8

Vysvetlenie programu:

V prvom a druhom riadku programu sú príkazy určené pre programovacie prostredie, ktoré implementujú knižnicu <Atmega8_IO.h>.

Príkazy vo void loop(){} v svorkových zátvorkách:{} bežia v nekonečnom procese a opakujú sa.

V šiestom riadku zadávame podmienku pre senzor osvetlenia.
Ak je jeho hodnota väčšia ako 0, teda jeho hodnota=1, robot Cing vypne oba motory.
Ak je jeho hodnota 0, pokračuje dopredu na oboch motoroch aj so zapnutým bzučiakom.

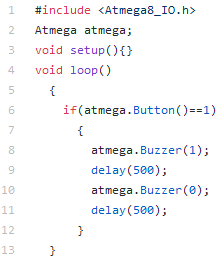
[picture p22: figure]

9

## 4. TLAČIDLO

V tejto kapitole si pripomenieme naše vedomosti o tlačidle a doplníme ich o nové poznatky.

Budeme potrebovať:

- Robota Cing
- Tlačidlo
- Bzučiak
- ICSP AVR programátor

Stratégia:

Robot Cing bude stáť na mieste. Ak stlačíme tlačidlo, bzučiak bude pípať.

Program:

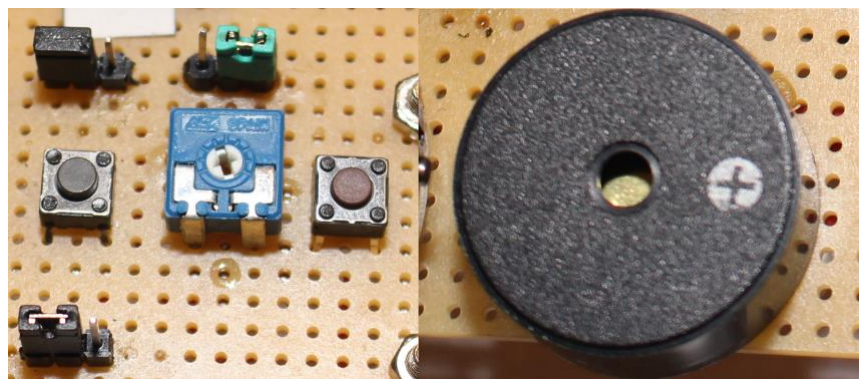
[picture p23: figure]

10

Vysvetlenie programu:

V prvom a druhom riadku programu sú príkazy určené pre programovacie prostredie, ktoré implementujú knižnicu <Atmega8_IO.h>.

Príkazy vo void loop(){} v svorkových zátvorkách:{} bežia v nekonečnom procese a opakujú sa.

V šiestom riadku vytvárame podmienku pre tlačidlo.

Ak je jeho hodnota 1, teda je stlačené, robot Cing zapne bzučiak, ktorý bude 500 milisekúnd bzučať a 500 milisekúnd bude vypnutý.

Ak je jeho hodnota 0, teda tlačidlo nie je stlačené, robot bude ticho a nehybne stáť na mieste.

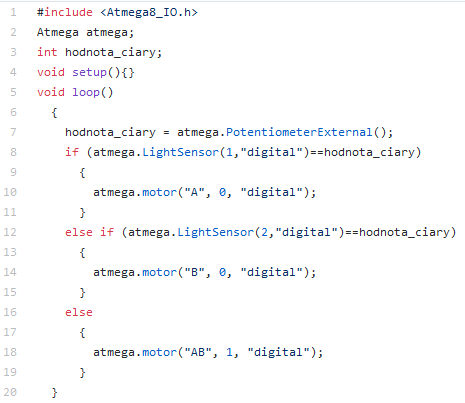
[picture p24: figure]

11

## 5. NASTAVUJEME HODNOTU

V tejto kapitole si ukážeme, akými rôznymi spôsobmi dokážeme pracovať s potenciometrom.

Budeme potrebovať:

- Robota Cing
- Potenciometer
- Svetelné senzor
- ICSP AVR programátor

Stratégia:

Robot Cing pôjde dopredu na oboch motoroch. Ak zaznamená prekážku vo vzdialenosti menej ako 20 cm, zastaví sa a začne húkať.

Program:

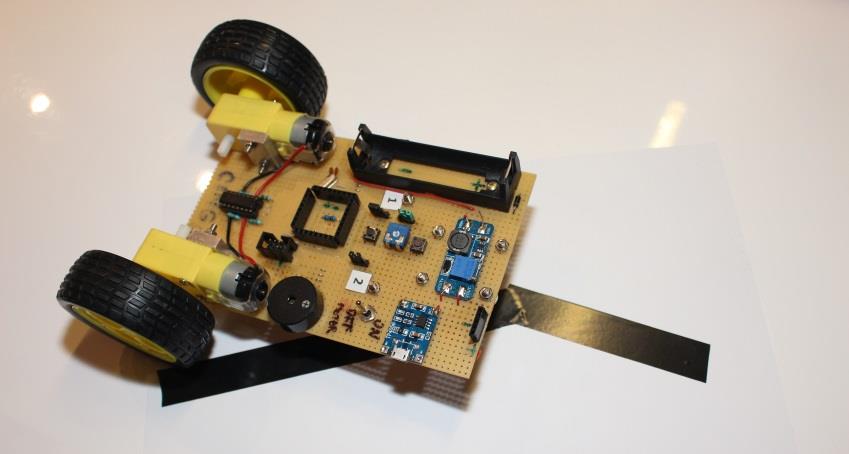
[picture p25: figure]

12

Vysvetlenie programu:

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

Príkazy vo void loop(){} v svorkových zátvorkách:{} bežia v nekonečnom procese a opakujú sa.

V treťom riadku programu vytvárame premennú hodnota čiary, ktorej v siedmom riadku zadefinujeme, že má rovnakú hodnotu ako potenciometer.

V ďalšej časti programu používame príkazy pre sledovanie čiary pomocou dvoch senzorov, avšak pri podmienke ich hodnotu neporovnávame s číslom, ale s premennou, ktorá má hodnotu ako potenciometer.

To znamená, že ak bude hodnota potenciometra 1, robot bude sledovať čiernu čiaru. Ak bude hodnota 0, robot bude sledovať bielu čiaru.

## 6. SVETELNÁ SIGNALIZÁCIA

Táto kapitola bude zaujímavá. Naučíme sa pracovať s ďalším novým komponentom – s farebnými LEDkami.

Budeme potrebovať:

- Robota Cing
- LEDky
- ICSP AVR programátor

Stratégia:

Robot Cing bude stáť na mieste. Najprv postupne zapne všetky LEDky na červeno, a potom ich vypne.

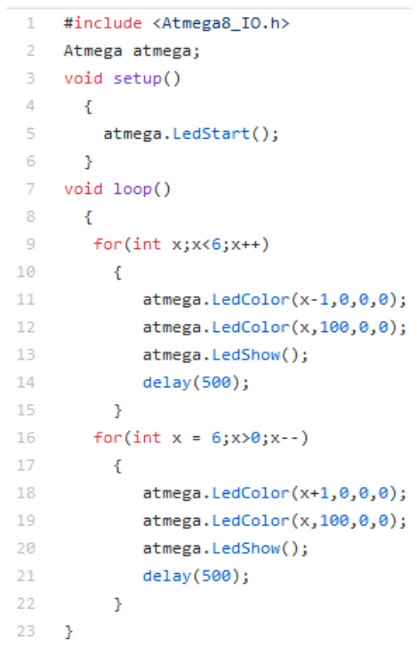
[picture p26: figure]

Program:

14

Vysvetlenie programu:

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

Príkazy vo void loop(){} v svorkových zátvorkách:{} bežia v nekonečnom procese a opakujú sa.

V piatom riadku programu povieme, že budeme používať LEDky.

V deviatom riadku vytvárame počítadlo. Keďže máme 6 LEDiek, proces zapnutia a vypnutia sa bude opakovať 6-krát.

LEDky majú štyri parametre:

1. číslo LEDky
2. hodnota červenej farby od 0-100%
3. hodnota zelenej farby do 0-100%
4. hodnota modrej farby od 0-100%

V trinástom riadku zapíname LEDky na 500 milisekúnd.

V prvom počítadle sa teda postupne zapnú LEDky na červenú farbu na všetkých 6 portoch.

V druhom počítadle sa všetky LEDky na 6 portoch postupne vypnú červenou farbou.

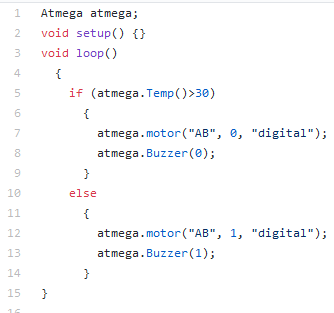
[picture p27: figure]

15

## 7. MERANIE TEPLOTY

V tejto kapitole si ukážeme, ako naprogramovať robota, aby súčasne používal tepelný senzor aj bzučiak.

Budeme potrebovať:

- Robota Cing
- Tepelný senzor
- Bzučiak
- ICSP AVR programátor

Stratégia:

Robot pôjde dopredu na oboch motoroch a so zapnutým bzučiakom. Ak ohrejeme tepelný senzor, robot sa zastaví a prestane húkať.

Program:

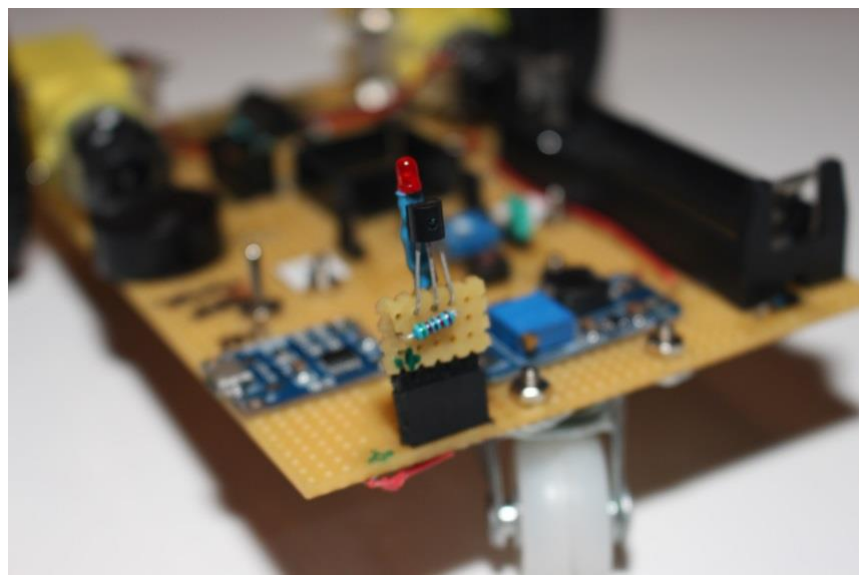
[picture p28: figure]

16

Vysvetlenie programu:

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

Príkazy vo void loop(){} v svorkových zátvorkách:{} bežia v nekonečnom procese a opakujú sa.

V piatom riadku vytvárame podmienku pre tepelný senzor.

Ak je jeho hodnota väčšia ako 30, robot sa zastaví
a prestane bzučať.

Ak je jeho hodnota menšia ako 30, robot pokračuje ďalej dopredu na oboch motoroch aj so zapnutým bzučiakom.

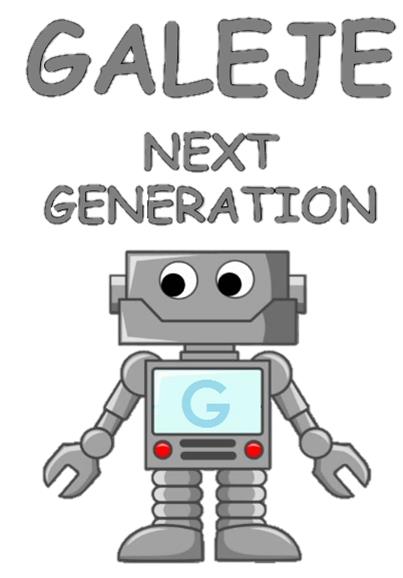
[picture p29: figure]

17

## Ďakujeme

18

## Ďakujeme, že ste si vybrali robota Cing

Vytvorili sme modely robota Cing a veríme, že vám pomôže pri vašich začiatkoch v robotike a elektronike, vyplnení voľného času a dúfame, že pre vás náš robot bude zábavnou formou vzdelávania sa.

Všetky informácie, programy i príručky k robotovi Cing nájdete na našej stránke: https://galeje.github.io/Cing

Budeme sa tešiť na vašu spätnú väzbu: robotcing@gmail.com

Autori:
Stanislav Jochman
Veronika Nemjová
Gymnázium, Alejová 1, Košice

2017 GalejeNextGen

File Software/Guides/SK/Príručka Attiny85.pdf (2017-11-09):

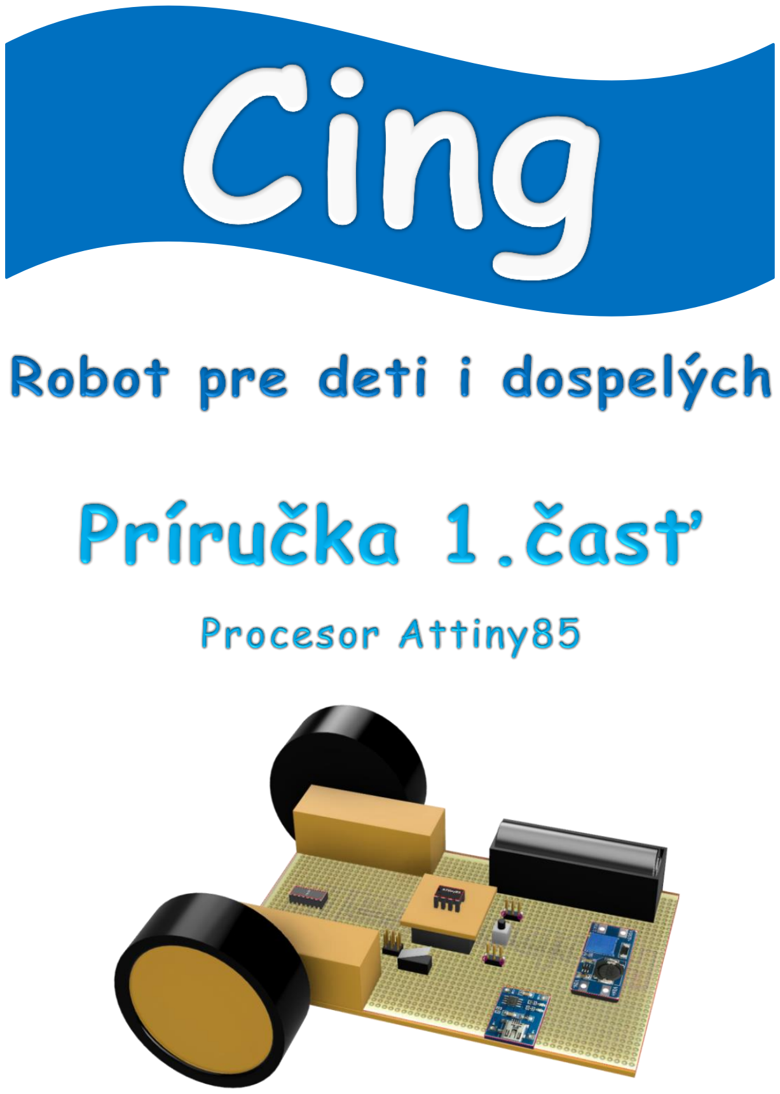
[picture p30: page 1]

;

## ÚVOD

V tejto krátkej príručke sa zoznámite so základnými príkazmi pre programovanie robota Cing a základnými algoritmami týkajúcich sa programovania. Je určená pre začiatočníkov, ale aj pokročilých, detí ale aj dospelých – skrátka pre každého, kto má záujem naučiť sa základy programovania.

Robot Cing nepoužíva vlastný programovací jazyk, ale Arduino knižnicu, ktorá umožňuje jednoduché naprogramovanie robota pre začiatočníkov a stredne pokročilých.

Pokročilí a skúsení používatelia môžu robota Cing programovať priamo v Arduino prostredí bez použitia knižnice.

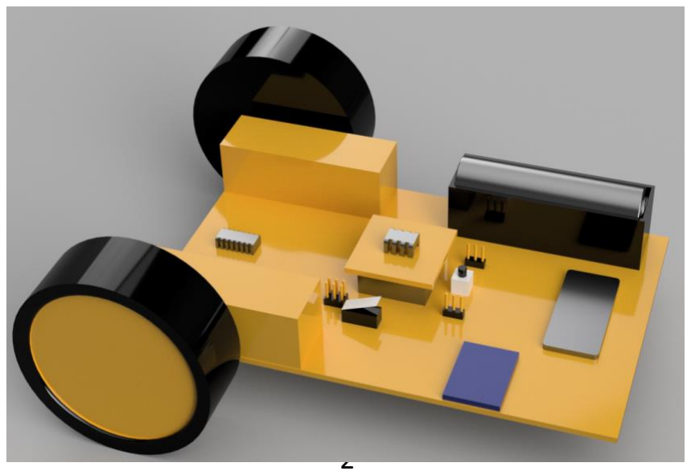
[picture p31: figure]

3

## OBSAH

## 1. ZOZNÁMME SA S ROBOTOM

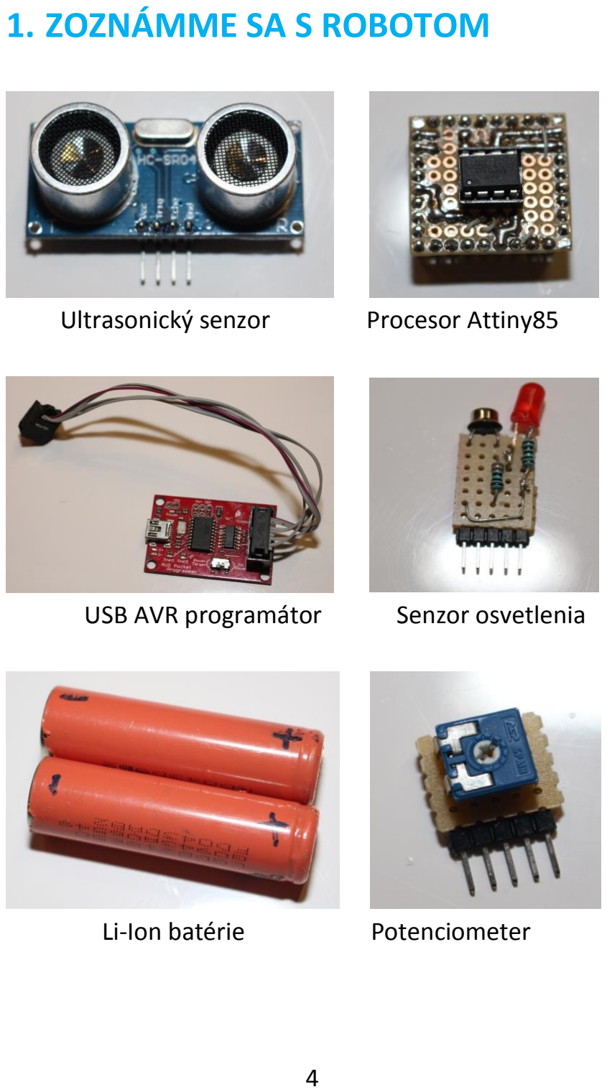
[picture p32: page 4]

4

Ultrasonický senzor | Procesor Attiny85
USB AVR programátor | Senzor osvetlenia
Li-Ion batérie | Potenciometer

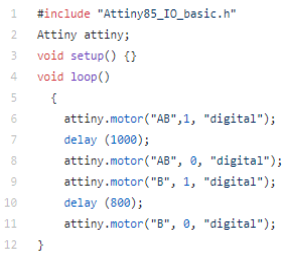
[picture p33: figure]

5

## 2. ZAČÍNAME S ROBOTOM

V tejto kapitole sa zoznámime s programovacím prostredím robota Cing a naučíme robota Cing pohnúť sa z miesta. Nebudeme používať žiadne senzory, pretože našou úlohou bude robota Cing rozhýbať.

Budeme potrebovať:
- Robota Cing
- ICSP ASP programátor

### - CHODENIE ROVNO A DOPRAVA

Stratégia:
Robot Cing sa bude pohybovať na oboch motoroch dopredu, na pravom motore doľava a na ľavom motore doprava.

Program:

6

Vysvetlenie programu:
V prvom a druhom riadku programu sú príkazy určené pre programovacie prostredie, ktoré povedia, že budeme používať zjednodušené príkazy pre Attiny85 (implementujú knižnicu <Attiny85_IO_basic.h>). Príkazy vo void loop(){} v svorkových zátvorkách:{} bežia v nekonečnom procese a opakujú sa.
Attiny.motor (“A”, 1, “digital”) → pomocou tohto príkazu robot Cing zapne motor v porte “A” na vstupe “digital”.
Prvý parameter, ktorý môže obsahovať “A”, ”B”, ”AB” určuje, pre ktorý motor/motory sa vzťahujú nasledujúce parametre príkazu.
Posledný parameter určuje spôsob zapínania motoru (“digital”, “analog”).
Vstup “digital” môže mať len dva parametre:
1 → zapnutý , 0 → vypnutý (1=100%).
Vstup “analog” môže mať parametre obsahujúce čísla od 0-100 vrátane. Na tomto vstupe zadávame počet percent.
100 → 100%-zapnutý, 0 → 0%-vypnutý

Attiny.motor (“A”, 33, ”analog”) → robot Cing zapne motor v porte “A” na vstupe “analog” na 33%.
delay (1000) → príkaz, pomocou ktorého bude robot Cing vykonávať predchádzajúci príkaz v čase v zátvorke; udáva sa v milisekundách
1000 milisekúnd = 1 sekunda

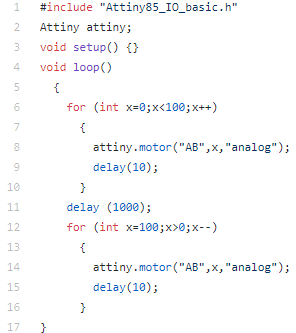
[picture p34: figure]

7

### - SPOMAĽOVANIE A ZRÝCHĽOVANIE

Stratégia:
Robot Cing sa bude pohybovať na oboch motoroch dopredu, pričom bude najprv postupne zrýchľovať, a potom bude spomaľovať.

Program:

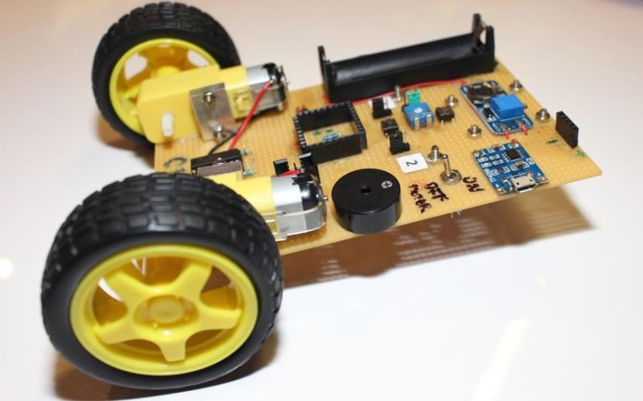
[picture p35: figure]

8

Vysvetlenie programu:

V prvom a druhom riadku programu sú príkazy určené pre programovacie prostredie, ktoré povedia, že budeme používať zjednodušené príkazy pre Attiny85 (implementujú knižnicu <Attiny85_IO_basic.h>).

Príkazy vo void loop(){} v svorkových zátvorkách:{} bežia v nekonečnom procese a opakujú sa.

V šiestom riadku programu vytvárame počítadlo, pre ktoré platí, že hodnota x=0, a kým je x<100, tak po každom pohnutí sa robota sa ku x pripočíta 1. Znamená to teda, že robot bude postupne zrýchľovať z 1% na 100% na parametri “analog” a následne spomaľovať zo 100% na 0% na parametri “analog.”

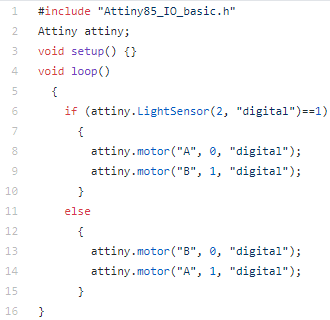
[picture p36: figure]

9

## 3. SLEDOVANIE ČIARY

V tejto kapitole si ukážeme, ako naprogramovať robota Cing, aby sa pohyboval po čiare.

Budeme potrebovať:
- Robota Cing
- ICSP ASP programátor
- 2x Svetelný senzor

### - POMOCOU JEDNÉHO SENZORA

Stratégia:
Robot Cing bude sledovať čiaru senzorom tak, že ak svetelný senzor nasníma čiaru na plátne, pohne pravým motorom dopredu. Ak čiaru nenasníma, pohne ľavým motorom.

Program:

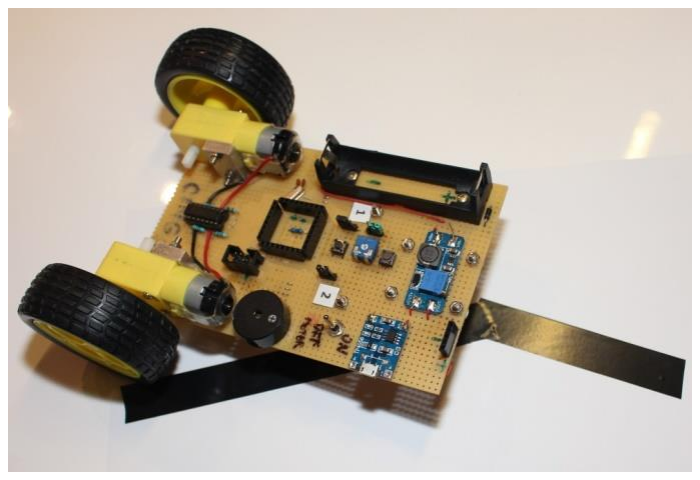
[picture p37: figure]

10

Vysvetlenie programu:
V prvom a druhom riadku programu sú príkazy určené pre programovacie prostredie, ktoré povedia, že budeme používať zjednodušené príkazy pre Attiny85 (implementujú knižnicu <Attiny85_IO_basic.h>). Príkazy vo void loop(){} v svorkových zátvorkách:{} bežia v nekonečnom procese a opakujú sa.
V šiestom riadku sa overuje hodnota svetelného senzora – ak je jeho hodnota rovná 0, vypne motor v porte B a zapne motor v porte A. Ak je jeho hodnota rovná 1, motor v porte A sa vypne a motor v porte B sa zapne.

### - POMOCOU DVOCH SENZOROV

Stratégia:
Robot Cing bude sledovať čiaru pomocou dvoch svetelných senzorov. Oba motory idú dopredu, pokiaľ jeden zo svetelných senzorov nenasníma čiaru. Ak ju nasníma, motor na tej strane sa zastaví.

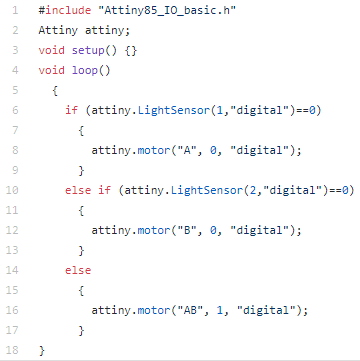
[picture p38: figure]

11

Program:

Vysvetlenie programu:
V prvom a druhom riadku programu sú príkazy určené pre programovacie prostredie, ktoré povedia, že budeme používať zjednodušené príkazy pre Attiny85 (implementujú knižnicu <Attiny85_IO_basic.h>). Príkazy vo void loop(){} v svorkových zátvorkách:{} bežia v nekonečnom procese a opakujú sa.
V šiestom riadku sa overuje podmienka pre svetelný senzor v porte 1, teda či je jeho hodnota menšia ako 1. Ak je jeho hodnota <1, zastaví motor v porte A.
Ak je hodnota väčšia, motor v porte A zapne.
V desiatom riadku sa overuje podmienka pre druhý svetelný senzor – v porte 2. Ak je jeho hodnota <1, zastaví motor v porte B.
Ak je hodnota väčšia, motor B sa zapne.

## 4. MERANIE TEPLOTY

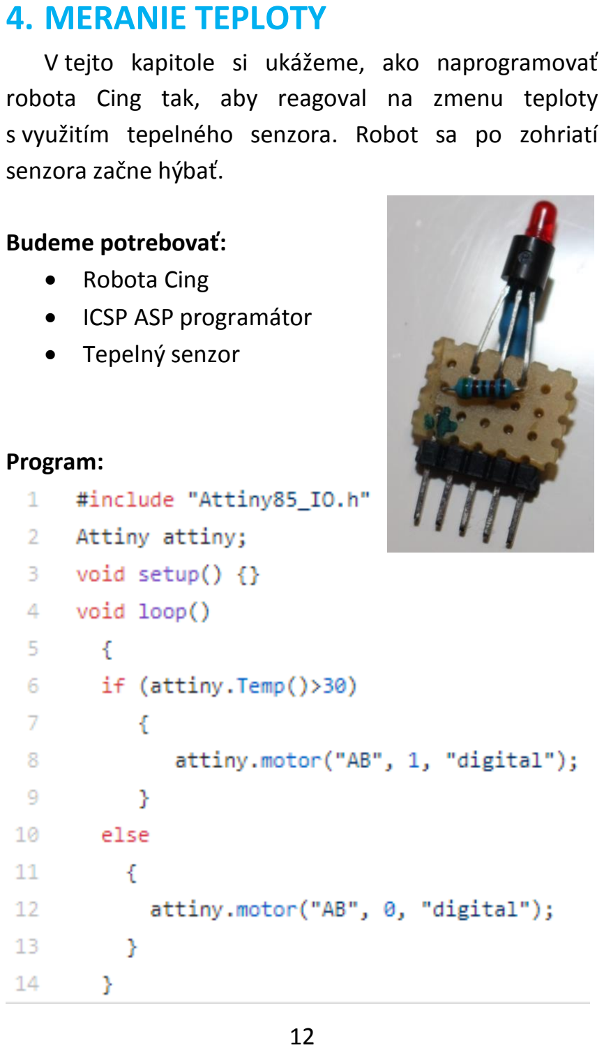
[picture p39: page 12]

12

V tejto kapitole si ukážeme, ako naprogramovať robota Cing tak, aby reagoval na zmenu teploty s využitím tepelného senzora. Robot sa po zohriatí senzora začne hýbať.

Budeme potrebovať:
- Robota Cing
- ICSP ASP programátor
- Tepelný senzor

Program:

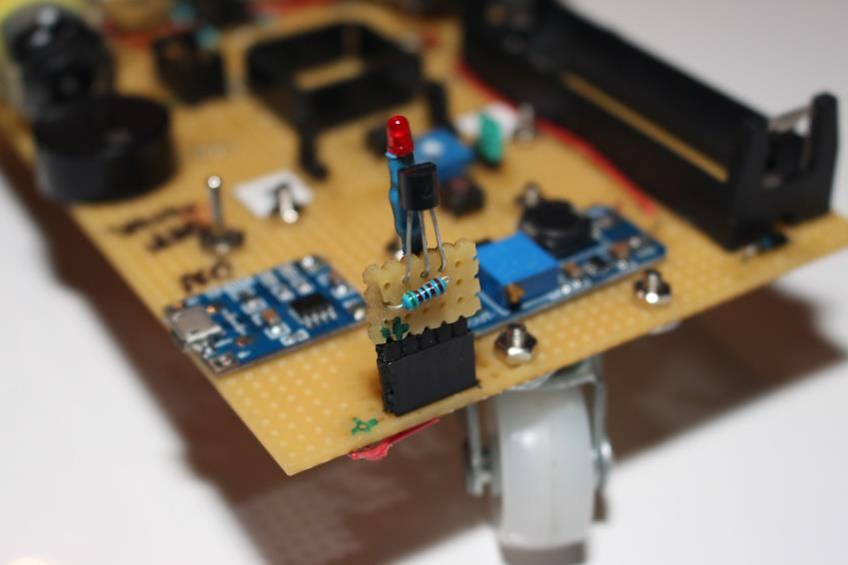
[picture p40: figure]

13

Vysvetlenie programu:
V prvom a druhom riadku programu sú príkazy určené pre programovacie prostredie, ktoré povedia, že budeme používať zjednodušené príkazy pre Attiny85 (implementujú knižnicu <Attiny85_IO.h>).
Príkazy vo void loop(){} v svorkových zátvorkách:{} bežia v nekonečnom procese a opakujú sa.
V šiestom riadku procedúry sa overuje hodnota tepelného senzora.
Ak je jeho hodnota väčšia ako 30 stupňov, zapne motory v portoch A a B. Ak je jeho hodnota menšia ako 30 stupňov, vypne motor v portoch AB.

## 5. PREKÁŽKY

V tejto kapitole si ukážeme, ako zastaviť pred prekážkou.

Budeme potrebovať:
- Robota Cing
- ICSP ASP programátor
- Svetelný senzor
- Ultrasonický senzor

### - ZASTAVENIE PRED PREKÁŽKOU

Stratégia:
Robot Cing pôjde stále rovno na motoroch “AB“. Ak ultrasonickým senzorom zaznamená prekážku vo vzdialenosti menšej ako 20 cm, zastaví sa.

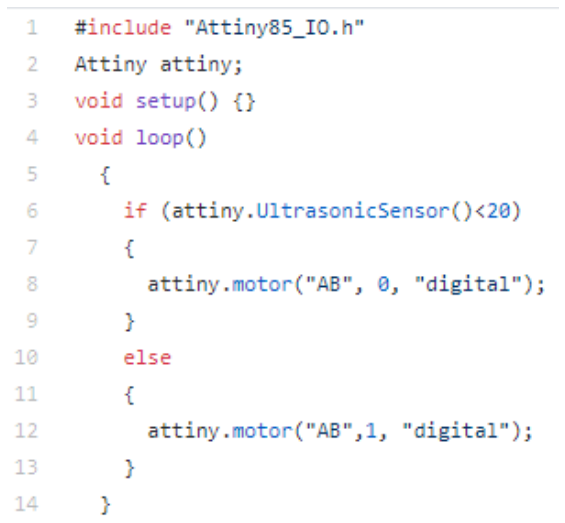
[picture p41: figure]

Program:

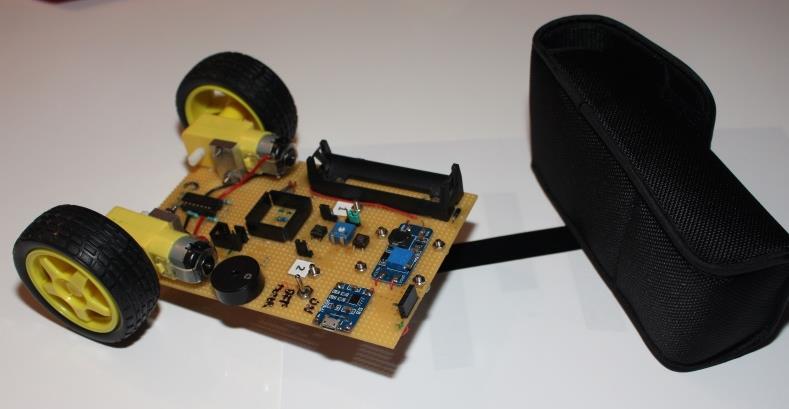
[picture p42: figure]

15

Vysvetlenie programu:
V prvom a druhom riadku programu sú príkazy určené pre programovacie prostredie, ktoré povedia, že budeme používať zjednodušené príkazy pre Attiny85 (implementujú knižnicu <Attiny85_IO.h>).
Príkazy vo void loop(){} v svorkových zátvorkách:{} bežia v nekonečnom procese a opakujú sa.
V šiestom | riadku | programu | zadávame | Cingovi
podmienku, ktorá | hovorí, | že | ak je | hodnota
ultrasonického senzora (vzdialenosť od prekážky) menšia ako 20, Cing zastaví oba motory.
Ak je vzdialenosť väčšia, pokračuje ďalej.

### - ZASTAVENIE SO SLEDOVANÍM ČIARY

Stratégia:

Cing bude sledovať čiaru, pričom ak zaznamená prekážku vo vzdialenosti menšej ako 20 cm, zastaví pred ňou.

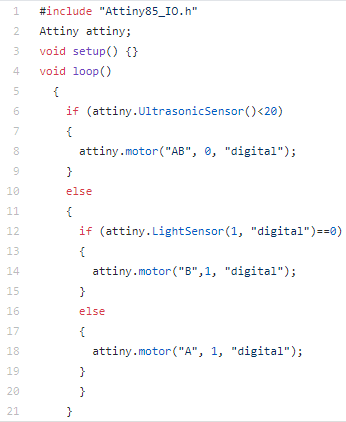
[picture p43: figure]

16

Program:

Vysvetlenie programu:
V prvom a druhom riadku programu sú príkazy určené pre programovacie prostredie, ktoré povedia, že budeme používať zjednodušené príkazy pre Attiny85 (implementujú knižnicu <Attiny85_IO.h>).
Príkazy vo void loop(){} v svorkových zátvorkách:{} bežia v nekonečnom procese a opakujú sa.
V šiestom riadku programu nastavujeme robotovi podmienku, že ak je hodnota ultrasonického senzora menšia ako 20, robot sa zastaví.
Ak je hodnota väčšia, robot pokračuje, pričom sleduje aj čiaru.

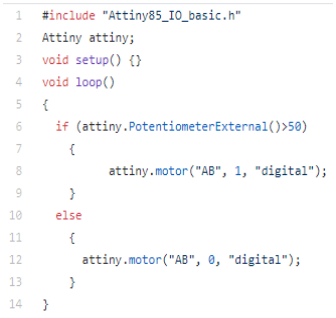
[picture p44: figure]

17

## 6. NASTAVUJEME HODNOTU

V tejto kapitole budeme vytvárať programy, pomocou ktorých bude Cing počítať čiary a na základe toho vykonávať ďalšie procesy.

Budeme potrebovať:
- Robota Cing
- ICSP ASP programátor
- Potenciometer

Stratégia:
Robot Cing bude chodiť, ak mu hodnotu na potenciometri nastavíme na viac ako 50%. Ak bude hodnota nižšia ako 50%, Cing bude stáť.

Program:

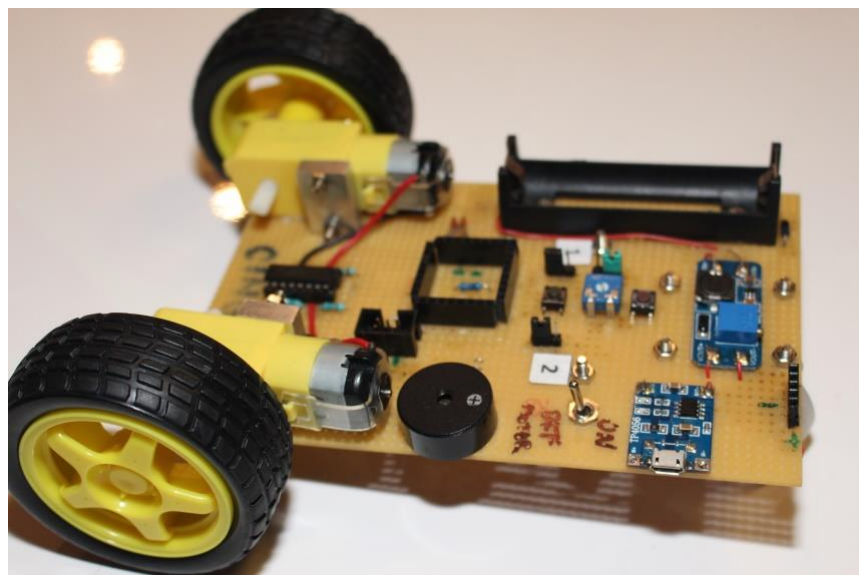
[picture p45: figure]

18

Vysvetlenie programu:
V prvom a druhom riadku programu sú príkazy určené pre programovacie prostredie, ktoré povedia, že budeme používať zjednodušené príkazy pre Attiny85 (implementujú knižnicu <Attiny85_IO_basic.h>). Príkazy vo void loop(){} v svorkových zátvorkách:{} bežia v nekonečnom procese a opakujú sa.
V šiestom riadku procedúry overujeme, či je na potenciometri nastavená hodnota vyššia ako 50%.
Ak je podmienka splnená, Cing pôjde dopredu.
Ak podmienka splnená nie je, robot ostane stáť.

## 7. POČÍTANIE ČIAR

V tejto kapitole budeme vytvárať programy, pomocou ktorých bude Cing počítať čiary a na základe toho vykonávať ďalšie procesy.

Budeme potrebovať:
- Robota Cing
- ICSP ASP programátor
- Svetelný senzor

Stratégia:
Robot Cing bude chodiť po plátne, na ktorom bude mať niekoľko čiar. Pomocou svetelného senzora zaznamená všetky čiary a vykoná, čo mu zadáme do príkazu.

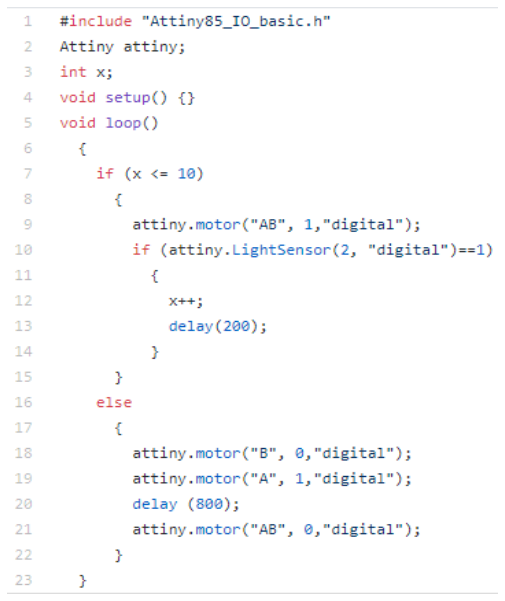
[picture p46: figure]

Program:

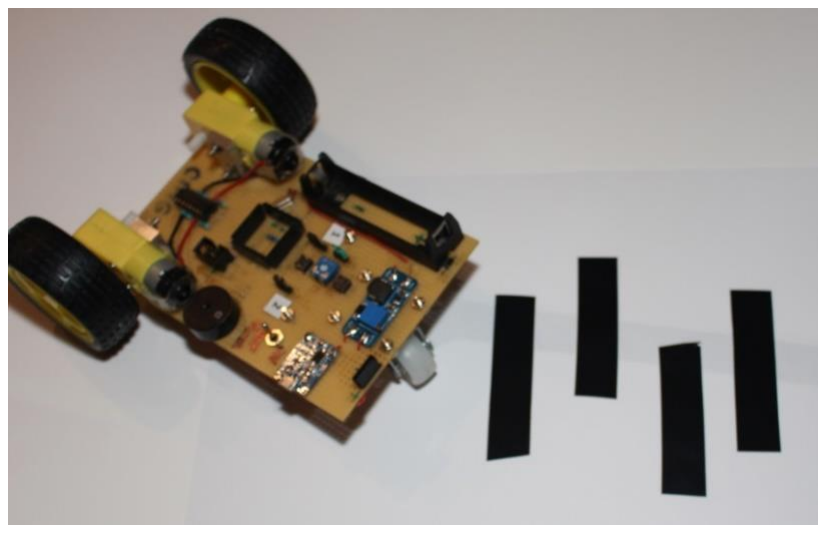
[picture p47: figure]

20

Vysvetlenie programu:
V prvom a druhom riadku programu sú príkazy určené pre programovacie prostredie, ktoré povedia, že budeme používať zjednodušené príkazy pre Attiny85 (implementujú knižnicu <Attiny85_IO_basic.h>). Príkazy vo void loop(){} v svorkových zátvorkách:{} bežia v nekonečnom procese a opakujú sa.
V treťom riadku procedúry vytvárame premennú x s hodnotou 0.
V siedmom riadku zadávame podmienku, ktorá hovorí, že program v zátvorkách sa bude opakovať, pokiaľ x <=10. Kým podmienka nebude splnená, robot pôjde dopredu, pričom bude overovať či svetelný senzor nenasnímal čiaru.
Ak ju nasnímal x++ pridá premennej hodnotu 1.
Ak x nadobudne hodnotu 10, vykoná sa proces v zátvorkách else.

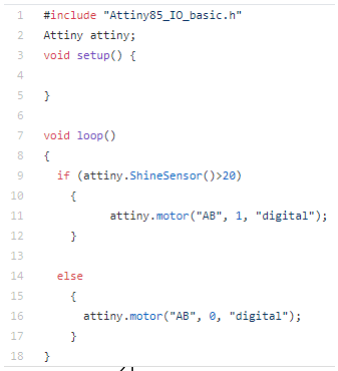
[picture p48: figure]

21

## 8. OSVETLENIE

V tejto kapitole si vytvoríme program, ktorým rozhýbeme robota Cing pomocou senzora osvetlenia.

Budeme potrebovať:
- Robota Cing
- ICSP ASP programátor
- Senzor osvetlenia

Stratégia:
Robot Cing bude stáť. Ak osvetlíme senzor osvetlenia na viac ako 20%, Cing sa začne hýbať dopredu.

Program:

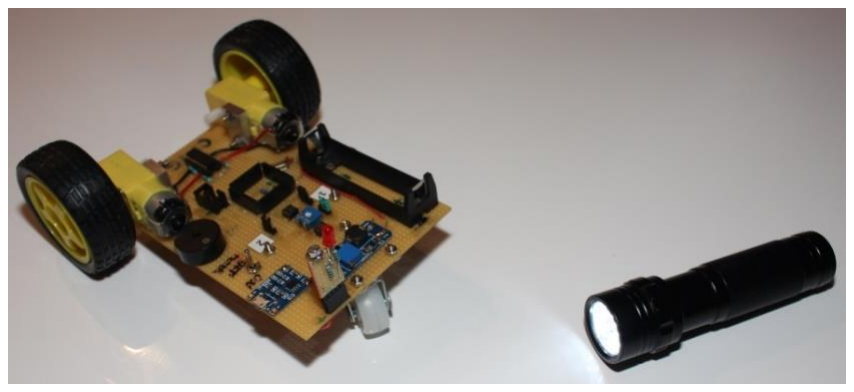
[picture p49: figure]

22

Vysvetlenie programu:
V prvom a druhom riadku programu sú príkazy určené pre programovacie prostredie, ktoré povedia, že budeme používať zjednodušené príkazy pre Attiny85 (implementujú knižnicu <Attiny85_IO_basic.h>). Príkazy vo void loop(){} v svorkových zátvorkách:{} bežia v nekonečnom procese a opakujú sa.
V deviatom riadku procedúry sa overuje podmienka pre senzor osvetlenia.
Ak je osvetlený na viac ako 20%, robot Cing pôjde dopredu na oboch motoroch.
Ak podmienka splnená nie je, robot Cing bude stáť.

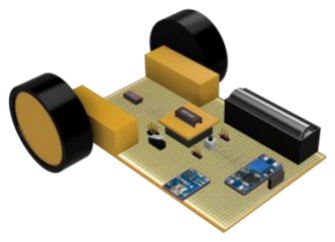
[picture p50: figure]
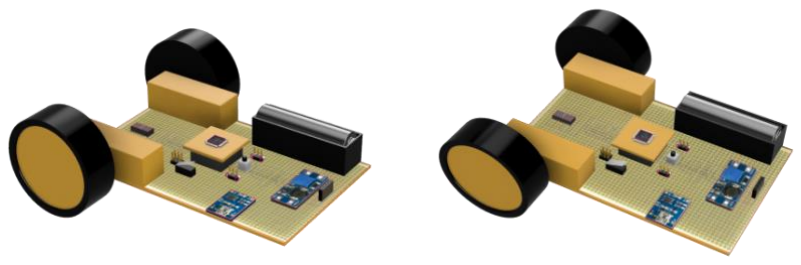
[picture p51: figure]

23

## Modely robota Cing

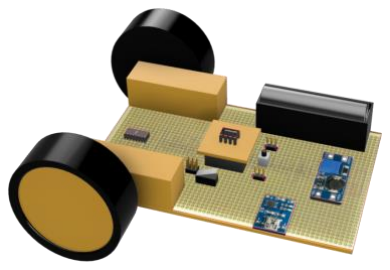
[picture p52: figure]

1.časť
Attiny85

2.časť
Attiny84

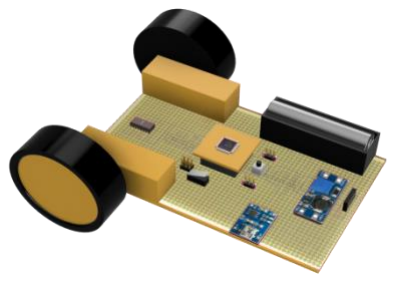
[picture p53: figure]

3.časť
Atmega8

4.časť
Attiny13

5.časť
Atmega328

6.časť
Atmega32u4

24

## Ďakujeme, že ste si vybrali robota Cing

Veríme, že vám pomôže pri vašich začiatkoch, vyplnení voľného času a dúfame, že pre vás bude zábavnou formou učenia.

Vytvorili sme modely robota Cing, ktoré podporujú ľudí pri ich začiatkoch
v programovaní tak, ako ich aj učia nové veci ľahkou a hravou formou.

Budeme radi, za vašu spätnú väzbu (odkaz na našej stránke).

Viac informácií na našej stránke: https://galeje.github.io/Cing

Autori:
Stanislav Jochman
Veronika Nemjová
Gymnázium, Alejová 1, Košice

2017 GalejeNextGen

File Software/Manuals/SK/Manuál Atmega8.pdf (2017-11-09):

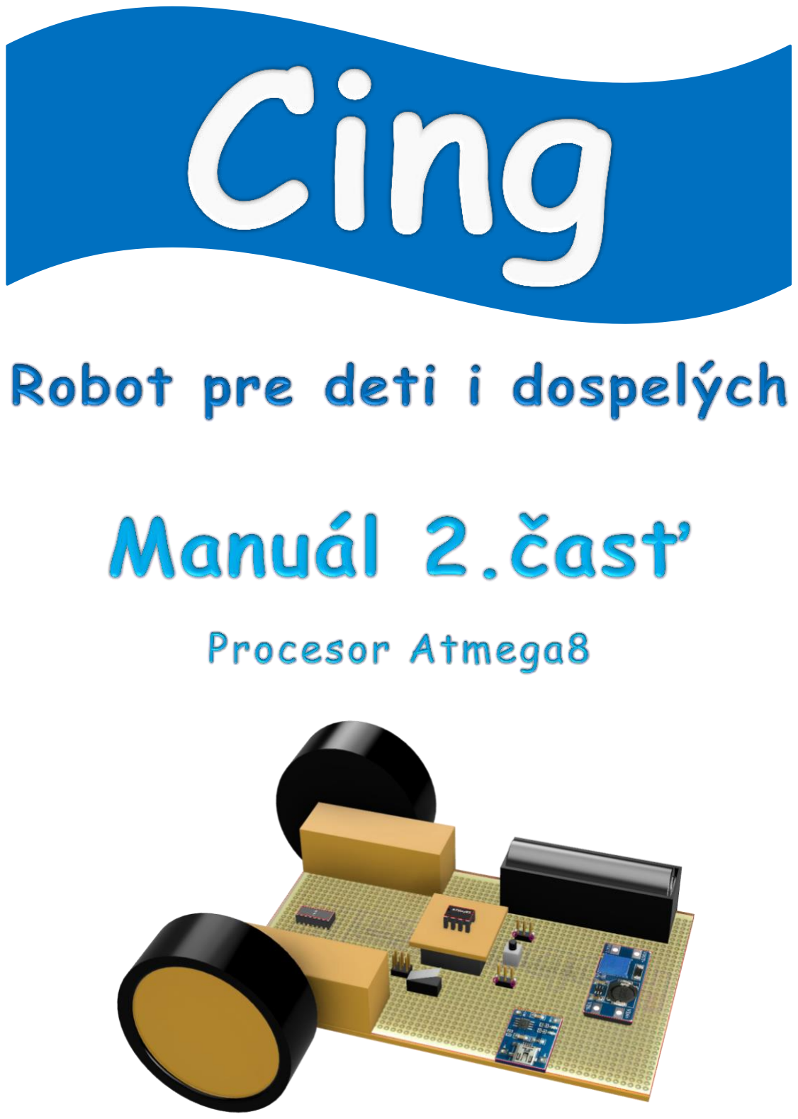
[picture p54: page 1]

;


2

### ÚVOD

V tomto krátkom manuáli k ďalšej časti zo séria robota Cing nájdete ako správne zapojiť ledky do modelu robota Cing.

### OBSAH


3

### 1. ZAPOJENIE SENZOROV

V tejto čassti nám žiadne nové senzory nepribudli. Vyskúšajte si teda, ako fungujú nové ledky.

- LEDky

4

Ďakujeme, že ste si vybrali robota Cing

Veríme, že vám pomôže pri vašich začiatkoch, vyplnení voľného času a dúfame, že pre vás bude zábavnou formou učenia.

Vytvorili sme modely robota Cing, ktoré podporujú ľudí pri ich začiatkoch
v programovaní tak, ako ich aj učia nové veci ľahkou a hravou formou.

Budeme radi, za vašu spätnú väzbu (odkaz na našej stránke).

Viac informácií na našej stránke: https://galeje.github.io/Cing

Autori:
Stanislav Jochman
Veronika Nemjová
Gymnázium, Alejová 1, Košice

2017 GalejeNextGen

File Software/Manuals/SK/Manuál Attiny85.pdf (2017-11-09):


;


2

## ÚVOD

V tomto krátkom manuáli k prvej časti zo séria robota Cing nájdete základné kroky a postupy, ako nainštalovať ovládače, programy a dokumenty potrebné k programovaniu robota Cing. Pre inštaláciu je potrebné inštalačné CD, ktoré ste dostali.

3

## OBSAH


4

## 1. INŠTALÁCIA OVLÁDAČA

Najprv si stiahnite obsah CD do počítača. Pre inštaláciu ovládača:

1. Otvorte priečinok Ovládače
2. Otvorte aplikáciu Ovládače
3. Kliknite na Options
4. Zvoľte možnosť List All Devices
5. Vyberte #Unknown Device
6. Pomocou šípok nastavte libusb-win32 (v1.2.6.0)
7. Kliknite na tlačidlo Install


5

## 2. ZAPOJENIE SENZOROV

Ak máte senzor zapojený správne, bude svietiť. Ak je zapojený nesprávne, bude svietiť slabo alebo vôbec. Nemusíte sa báť, že robota pokazíte, je chránený proti zlému zapojeniu komponentov.

### - Senzor osvetlenia

### - Tepelný senzor


6

### - Ultrasonický senzor

### - Potenciometer


7

## 3. ARDUINO PORTABLE

Aby sa vám ľahšie programovalo, vytvorili sme pre vás Arduino portable. Je to vylepšená verzia Arduina, v ktorej sa ľahko zorientujete, nakoľko si viete zvoliť iba možnosti kompatibilné s robotom Cing. Aby ste nemuseli opisovať niektoré programy z príručky, v Arduino portable nájdete aj príklady správnych riešení.

### - Knižnice


8

### - Programátor

### - Doska


9

### - Príklady programov

10

## Ďakujeme, že ste si vybrali robota Cing

Veríme, že vám pomôže pri vašich začiatkoch, vyplnení voľného času a dúfame, že pre vás bude zábavnou formou učenia.

Vytvorili sme modely robota Cing, ktoré podporujú ľudí pri ich začiatkoch
v programovaní tak, ako ich aj učia nové veci ľahkou a hravou formou.

Budeme radi, za vašu spätnú väzbu (odkaz na našej stránke).

Viac informácií na našej stránke: https://galeje.github.io/Cing

Autori:
Stanislav Jochman
Veronika Nemjová
Gymnázium, Alejová 1, Košice

2017 GalejeNextGen

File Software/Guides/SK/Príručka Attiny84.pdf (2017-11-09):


;


2

## ÚVOD

V prvej časti zo série robota Cing sme si ukázali najzákladnejšie pohyby robota, pohyby vpred a do strán a tiež sme si vyskúšali prácu z rôznymi senzormi a parametrami.
V tejto príručke si ukážeme, ako vylepšiť pohyby, vytvárať zložitejšie príkazy, vyskúšame si prácu s novými senzormi či komponentmi a naučíme sa, ako správne používať príkazy. Navyše ku kapitolám pribudnú úlohy, takže sa nemusíte obávať, že by toho bolo málo. Opäť sa budeme vzdelávať hravou a zábavnou formu. Nemusíte sa báť, že to bude ťažké – práve naopak!

Vďaka poznatkom a vedomostiam z predchádzajúcej časti to bude ešte jednoduchšie!

3

## OBSAH

## 1. ZOZNÁMME SA S NOVINKAMI


4

Bzučiak | Model Cing Attiny84
Attiny84 | Tlačidlo

Model Cing – Pohľad zhora


5

## 2. POKRAČUJEME V POHYBE

V predchádzajúcej časti | sme | sa | zoznámili
s programovacím prostredím robota Cing a naučili robota Cing pohnúť sa z miesta. S týmto procesorom však pribudla aj funkcia cúvanie. V tejto kapitole si ukážeme, ako naprogramovať Cinga tak, aby sa hýbal nielen dopredu, ale aj dozadu.

Budeme potrebovať:
- Robota Cing
- ICSP ASP programátor

### - CHODENIE ROVNO A DOZADU

Stratégia:
Robot Cing sa bude pohybovať na oboch motoroch dopredu nejakú dobu, a potom cúvne naspäť dozadu.

Program:

6

Vysvetlenie programu:
V prvom a druhom riadku programu sú príkazy určené pre programovacie prostredie, ktoré implementujú knižnicu <Attiny84_IO_basic.h>.
Príkazy vo void loop(){} v svorkových zátvorkách:{} bežia v nekonečnom procese.
V šiestom riadku programu zapíname motory v portoch “AB“ na 1000 milisekúnd (1 sekundu). Potom tieto motory zapneme na parameter -1, čo znamená, že motory v portoch “AB“ pôjdu aj naďalej, avšak nie dopredu, ale dozadu. Teda na rozlíšenie smeru pohybu kolies používame znamienko -.
Ak ku parametru nedáme znamienko, znamená to, že sa robot bude hýbať dopredu.

### - SPOMAĽOVANIE A ZRÝCHĽOVANIE

Stratégia:
Pri | tomto | programe | využijeme | znalosti
z predchádzajúcej časti robota Cing. Robot Cing bude postupne zrýchľovať dopredu a potom to isté zopakuje aj smerom dozadu.


7

Program:


8

Vysvetlenie programu:
Začiatok programu je rovnaký ako v minulej časti.
V deviatom riadku programu vytvárame počítadlo, pre ktoré platí, že hodnota x=0, a kým je x<100, tak po každom pohnutí sa robota sa ku x pripočíta 1. Znamená to teda, že robot bude postupne zrýchľovať z 1% na 100% na parametri “analog” a následne spomaľovať zo 100% na 0% na parametri “analog.”
Program pokračuje | s rovnakými | príkazmi, avšak
namiesto parametra x sme nastavili parameter –x. Znamená to teda, že robot Cing bude najprv zrýchľovať a spomaľovať smerom dopredu, a potom zrýchľovať a spomaľovať popri cúvaní.


9

## 3. PREKÁŽKY

V tejto kapitole si ukážeme, ako obísť prekážku dookola alebo po čiare.

Budeme potrebovať:
- Robota Cing
- ICSP ASP programátor
- Svetelný senzor
- Ultrasonický senzor

### - OBCHÁDZKA PREKÁŽKY

Stratégia:
Robot Cing pôjde stále rovno na motoroch “AB“. Ak ultrasonickým senzorom zaznamená prekážku
vo vzdialenosti menšej ako 20 cm, obíde ju podľa toho, ako mu to zvolíme v programe.


10

Program:

11

Vysvetlenie programu:
V prvom a druhom riadku programu sú príkazy, ktoré implementujú knižnicu <Attiny84_IO.h>.
Príkazy vo void loop(){} v svorkových zátvorkách:{} bežia v nekonečnom procese a opakujú sa.
V deviatom riadku programu overujeme hodnotu ultrasonického senzora.
Ak je prekážka vzdialená od robota na viac ako 20 cm, robot Cing pokračuje ďalej dopredu na motoroch “AB“. Ak je prekážka bližšie ako 20 cm, robot začne prekážku obchádzať tak, že sa najprv otočí doľava a potom doprava a následne pôjde na oboch motoroch dopredu. Tento proces zopakuje štyrikrát, pretože sme mu v jedenástom riadku programu zadali počítadlo, ktoré hovorí, že kým x<4 tak robot Cing bude tento proces opakovať. Tento proces zopakuje, kým bude mať x hodnoty:
x = 0; x = 1; x = 2; x = 3
Za vykonaním každého procesu pripočíta ku x 1.

### - OBCHÁDZKA SO SLEDOVANÍM ČIARY

Stratégia:
Robot Cing pôjde stále rovno na motoroch “AB“. Ak ultrasonickým senzorom zaznamená prekážku
vo vzdialenosti menšej ako 20 cm, obíde prekážku po čiare, ktorá je vedľa prekážky.


12

Program:


13

Vysvetlenie programu:
V prvom a druhom riadku programu sú príkazy, ktoré implementujú knižnicu <Attiny85_IO.h>.
Príkazy vo void loop(){} v svorkových zátvorkách:{} bežia v nekonečnom procese a opakujú sa.
V deviatom overujeme hodnotu ultrasonického senzora. Ak je jeho hodnota menšia ako 20, robot sa zastaví.
Ak je hodnota väčšia, robot pokračuje, pričom sleduje aj čiaru.


14

## 4. OSVETLENIE

V tejto kapitole si ukážeme, ako obísť prekážku dookola alebo po čiare.

Budeme potrebovať:
- Robota Cing
- ICSP ASP programátor
- Senzor osvetlenia
- Svetelný senzor

Stratégia:
Ak senzor osvetlíme na viac ako 20%, robot zastane. Ak ho neosvetlíme, robot bude nasledovať čiaru.

Program:


15

Vysvetlenie programu:
V prvom a druhom riadku programu sú príkazy, ktoré implementujú knižnicu <Attiny84_IO.h>.
Príkazy vo void loop(){} v svorkových zátvorkách:{} bežia v nekonečnom procese a opakujú sa.
V treťom riadku zadávame, že ak v programe zadáme slovo “ciara“, priradí mu hodnotu 0.
V siedmom riadku overujeme podmienku senzoru osvetlenia.
Ak je jeho hodnota viac ako 20, robot Cing sa zastaví na oboch motoroch.
Ak je jeho hodnota menšia ako 20, robot Cing pôjde ďalej po čiare.
V trinástom riadku overujeme podmienku pre svetelný senzor, avšak neporovnávame ju priamo s hodnotou 0, ale porovnávame ju so slovom ciara, ktoré ma hodnotu 0.
Takto si v programoch vieme definovať pojmy a ich hodnoty.


16

## 5. TLAČIDLO

V tejto kapitole si ukážeme, ako obísť prekážku dookola alebo po čiare.

Budeme potrebovať:
- Robota Cing
- ICSP ASP programátor

Stratégia:
Robot Cing pôjde pôjde dopredu a doprava, pokiaľ bude tlačidlo stisnuté. Ak tlačidlo stlačené nebude,
robot
bude
stáť.

Program:


17

Vysvetlenie programu:
V prvom a druhom riadku programu sú príkazy, ktoré implementujú knižnicu <Attiny84_IO.h>.
Príkazy vo void loop(){} v svorkových zátvorkách:{} bežia v nekonečnom procese a opakujú sa.
V šiestom riadku programu overujeme, či je tlačidlo zapnuté alebo vypnuté.
Vo ôsmom riadku máme podmienku while(true), ktorá hovorí, že kým bude podmienka v if platiť, bude vykonávať súbor príkazov v zátvorke.
Ak podmienka platiť nebude, vykoná sa príkaz v zátvorke else.
Program teda hovorí, že pokiaľ bude tlačidlo stlačené, robot Cing pôjde dopredu a doprava.
Ak tlačidlo stlačené nebude, Cing bude stáť.


18

## 6. BZUČIAK

V tejto kapitole si ukážeme, ako obísť prekážku dookola alebo po čiare.

Budeme potrebovať:
- Robota Cing
- ICSP ASP programátor
- Bzučiak

Stratégia:
Bzučiak bude sekundu zapnutý, a potom sekundu vypnutý.

Program:


19

Vysvetlenie programu:
V prvom a druhom riadku programu sú príkazy, ktoré implementujú knižnicu <Attiny84_IO.h>.
Príkazy vo void loop(){} v svorkových zátvorkách:{} bežia v nekonečnom procese a opakujú sa.
V siedmom riadku hovoríme, že zapneme bzučiak na sekundu. Potom sa bzučiak na sekundu vypne.

20

## Ďakujeme, že ste si vybrali robota Cing

Vytvorili sme modely robota Cing a veríme, že vám pomôže pri vašich začiatkoch v robotike a elektronike, vyplnení voľného času a dúfame, že pre vás náš robot bude zábavnou formou vzdelávania sa.

Všetky informácie, programy i príručky k robotovi Cing nájdete na našej stránke: https://galeje.github.io/Cing

Budeme sa tešiť na vašu spätnú väzbu: robotcing@gmail.com

Autori:
Stanislav Jochman
Veronika Nemjová
Gymnázium, Alejová 1, Košice

2017 GalejeNextGen

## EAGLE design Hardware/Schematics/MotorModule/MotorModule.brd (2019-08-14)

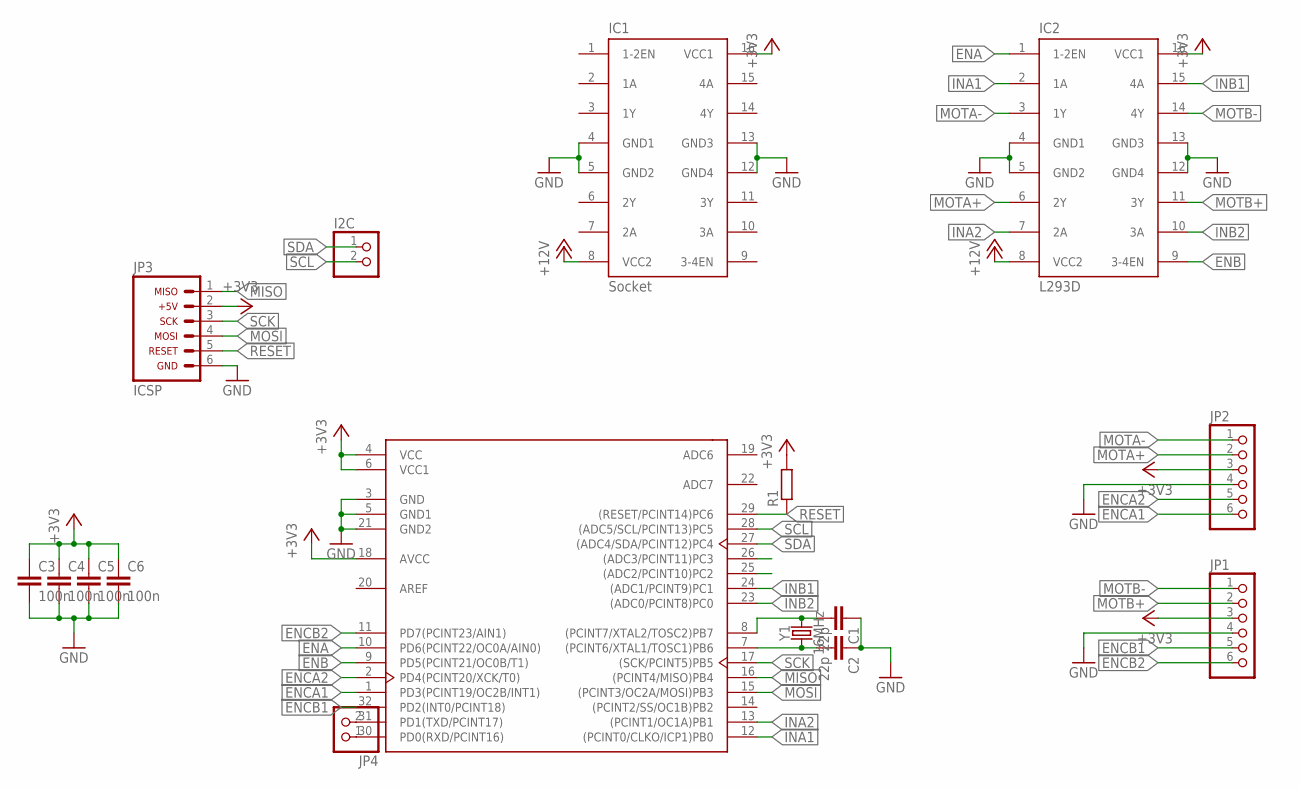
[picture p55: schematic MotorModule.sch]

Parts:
C1, C2: 22p; C1206
C3, C4, C5, C6: 100n; C1206
I2C: PINHD-1X2; 1X02
IC1: Socket; L293
IC2: L293D; L293
JP1, JP2: PINHD-1X6/90; 1X06/90
JP3: ICSP_HEADER
JP4: PINHD-1X2; 1X02
R1: R-EU_M1206; M1206
U1: ATMEGA328P-AU; TQFP-32
Y1: 16MHz; CRYSTAL-SMD-5X3.2-4PAD

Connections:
+3V3: C3.1, C4.1, C5.1, C6.1, IC1.16 (VCC1), IC2.16 (VCC1), JP1.3, JP2.3, JP3.2, R1.2, U1.4 (VCC), U1.6 (VCC1), U1.18 (AVCC)
+12V: IC1.8 (VCC2), IC2.8 (VCC2)
AREF: U1.20 (AREF)
ENA: IC2.1 (1-2EN), U1.10 (PD6(PCINT22/OC0A/AIN0))
ENB: IC2.9 (3-4EN), U1.9 (PD5(PCINT21/OC0B/T1))
ENCA1: JP2.6, U1.1 (PD3(PCINT19/OC2B/INT1))
ENCA2: JP2.5, U1.2 (PD4(PCINT20/XCK/T0))
ENCB1: JP1.5, U1.32 (PD2(INT0/PCINT18))
ENCB2: JP1.6, U1.11 (PD7(PCINT23/AIN1))
GND: C1.1, C2.1, C3.2, C4.2, C5.2, C6.2, IC1.4 (GND1), IC1.5 (GND2), IC1.12 (GND4), IC1.13 (GND3), IC2.4 (GND1), IC2.5 (GND2), IC2.12 (GND4), IC2.13 (GND3), JP1.4, JP2.4, JP3.6, U1.3 (GND), U1.5 (GND1), U1.21 (GND2)
INA1: IC2.2 (1A), U1.12 ((PCINT0/CLKO/ICP1)PB0)
INA2: IC2.7 (2A), U1.13 ((PCINT1/OC1A)PB1)
INB1: IC2.15 (4A), U1.24 ((ADC1/PCINT9)PC1)
INB2: IC2.10 (3A), U1.23 ((ADC0/PCINT8)PC0)
MISO: JP3.1, U1.16 ((PCINT4/MISO)PB4)
MOSI: JP3.4, U1.15 ((PCINT3/OC2A/MOSI)PB3)
MOTA+: IC2.6 (2Y), JP2.2
MOTA-: IC2.3 (1Y), JP2.1
MOTB+: IC2.11 (3Y), JP1.2
MOTB-: IC2.14 (4Y), JP1.1
unnamed: C1.2, U1.8 ((PCINT7/XTAL2/TOSC2)PB7), Y1.3 (2)
unnamed: C2.2, U1.7 ((PCINT6/XTAL1/TOSC1)PB6), Y1.1
unnamed: JP4.1, U1.30 (PD0(RXD/PCINT16))
unnamed: JP4.2, U1.31 (PD1(TXD/PCINT17))
RESET: JP3.5, R1.1, U1.29 ((RESET/PCINT14)PC6)
SCK: JP3.3, U1.17 ((SCK/PCINT5)PB5)
SCL: I2C.2, U1.28 ((ADC5/SCL/PCINT13)PC5)
SDA: I2C.1, U1.27 ((ADC4/SDA/PCINT12)PC4)

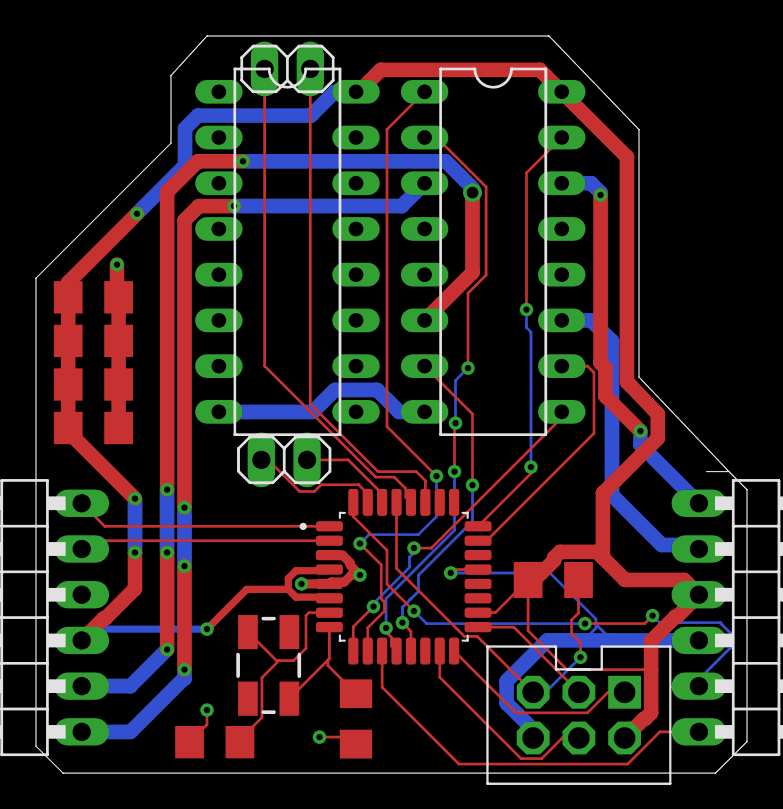
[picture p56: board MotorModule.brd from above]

Board: 2 copper layers, 39.5 x 41.0 mm, 16 parts (0 on the bottom side), 27 nets.

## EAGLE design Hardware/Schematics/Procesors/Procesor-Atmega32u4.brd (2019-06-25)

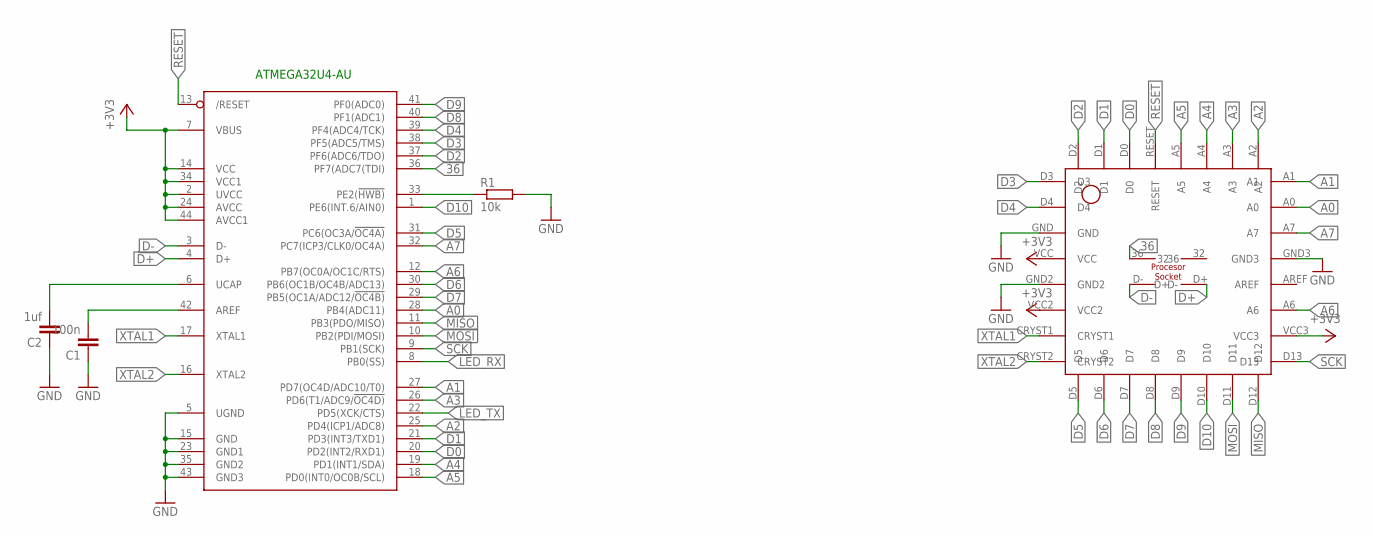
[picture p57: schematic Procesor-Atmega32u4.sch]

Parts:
ATMEGA32U4-AU: ATMEGA32U4-AU; TQFP44
C1: 100n; C1206
C2: 1uf; C1206K
R1: 10k; R1206
U$2: PROCESSOR-SOCKET; PROCESOR

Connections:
36: ATMEGA32U4-AU.36 (PF7(ADC7(TDI)), U$2.36
+3V3: ATMEGA32U4-AU.2 (UVCC), ATMEGA32U4-AU.7 (VBUS), ATMEGA32U4-AU.14 (VCC), ATMEGA32U4-AU.24 (AVCC), ATMEGA32U4-AU.34 (VCC1), ATMEGA32U4-AU.44 (AVCC1), U$2.VCC, U$2.VCC2, U$2.VCC3
A0: ATMEGA32U4-AU.28 (PB4(ADC11)), U$2.A0
A1: ATMEGA32U4-AU.27 (PD7(OC4D/ADC10/T0)), U$2.A1
A2: ATMEGA32U4-AU.25 (PD4(ICP1/ADC8)), U$2.A2
A3: ATMEGA32U4-AU.26 (PD6(T1/ADC9/!OC4D)), U$2.A3
A4: ATMEGA32U4-AU.19 (PD1(INT1/SDA)), U$2.A4
A5: ATMEGA32U4-AU.18 (PD0(INT0/OC0B/SCL)), U$2.A5
A6: ATMEGA32U4-AU.12 (PB7(OC0A/OC1C/RTS)), U$2.A6
A7: ATMEGA32U4-AU.32 (PC7(ICP3/CLK0/OC4A)), U$2.A7
D0: ATMEGA32U4-AU.20 (PD2(INT2/RXD1)), U$2.D0
D1: ATMEGA32U4-AU.21 (PD3(INT3/TXD1)), U$2.D1
D2: ATMEGA32U4-AU.37 (PF6(ADC6/TDO)), U$2.D2
D3: ATMEGA32U4-AU.38 (PF5(ADC5/TMS)), U$2.D3
D4: ATMEGA32U4-AU.39 (PF4(ADC4/TCK)), U$2.D4
D5: ATMEGA32U4-AU.31 (PC6(OC3A/!OC4A)), U$2.D5
D6: ATMEGA32U4-AU.30 (PB6(OC1B/OC4B/ADC13)), U$2.D6
D7: ATMEGA32U4-AU.29 (PB5(OC1A/ADC12/!OC4B)), U$2.D7
D8: ATMEGA32U4-AU.40 (PF1(ADC1)), U$2.D8
D9: ATMEGA32U4-AU.41 (PF0(ADC0)), U$2.D9
D10: ATMEGA32U4-AU.1 (PE6(INT.6/AIN0)), U$2.D10
D+: ATMEGA32U4-AU.4 (D+), U$2.D+
D-: ATMEGA32U4-AU.3 (D-), U$2.D-
GND: ATMEGA32U4-AU.5 (UGND), ATMEGA32U4-AU.15 (GND), ATMEGA32U4-AU.23 (GND1), ATMEGA32U4-AU.35 (GND2), ATMEGA32U4-AU.43 (GND3), C1.1, C2.1, R1.2, U$2.GND, U$2.GND2, U$2.GND3
LED_RX: ATMEGA32U4-AU.8 (PB0(SS))
LED_TX: ATMEGA32U4-AU.22 (PD5(XCK/CTS))
MISO: ATMEGA32U4-AU.11 (PB3(PDO/MISO)), U$2.D12
MOSI: ATMEGA32U4-AU.10 (PB2(PDI/MOSI)), U$2.D11
unnamed: ATMEGA32U4-AU.42 (AREF), C1.2
unnamed: ATMEGA32U4-AU.6 (UCAP), C2.2
unnamed: ATMEGA32U4-AU.33 (PE2(!HWB)), R1.1
RESET: ATMEGA32U4-AU.13 (/RESET), U$2.RESET
SCK: ATMEGA32U4-AU.9 (PB1(SCK)), U$2.D13
XTAL1: ATMEGA32U4-AU.17 (XTAL1), U$2.CRYST1
XTAL2: ATMEGA32U4-AU.16 (XTAL2), U$2.CRYST2

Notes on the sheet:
ATMEGA32U4-AU

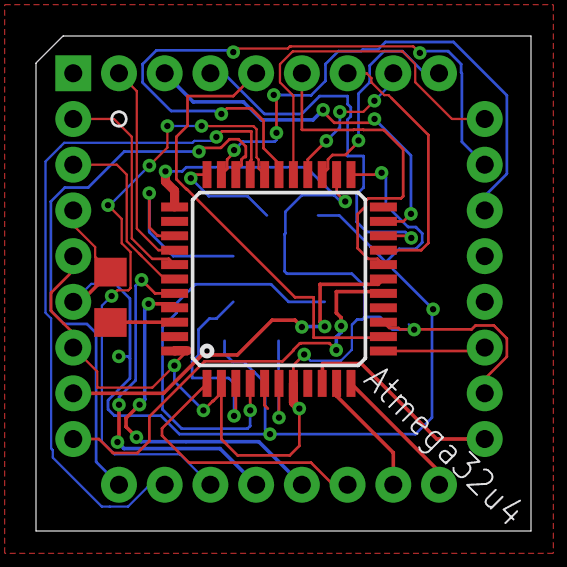
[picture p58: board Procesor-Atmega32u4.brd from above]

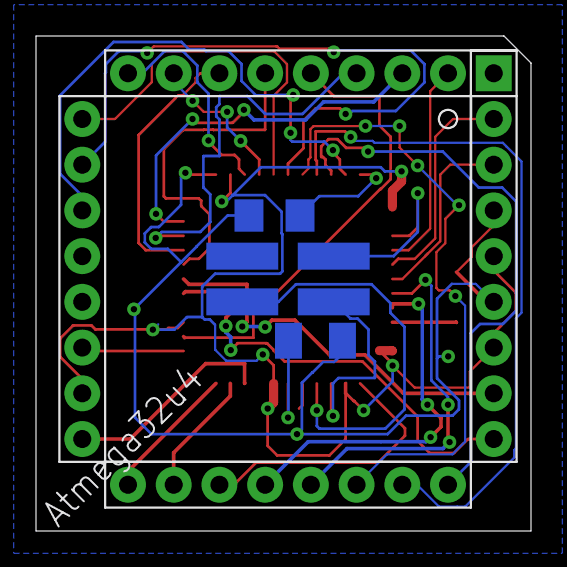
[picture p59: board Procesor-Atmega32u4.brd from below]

Board: 2 copper layers, 27.5 x 27.5 mm, 5 parts (2 on the bottom side), 33 nets.

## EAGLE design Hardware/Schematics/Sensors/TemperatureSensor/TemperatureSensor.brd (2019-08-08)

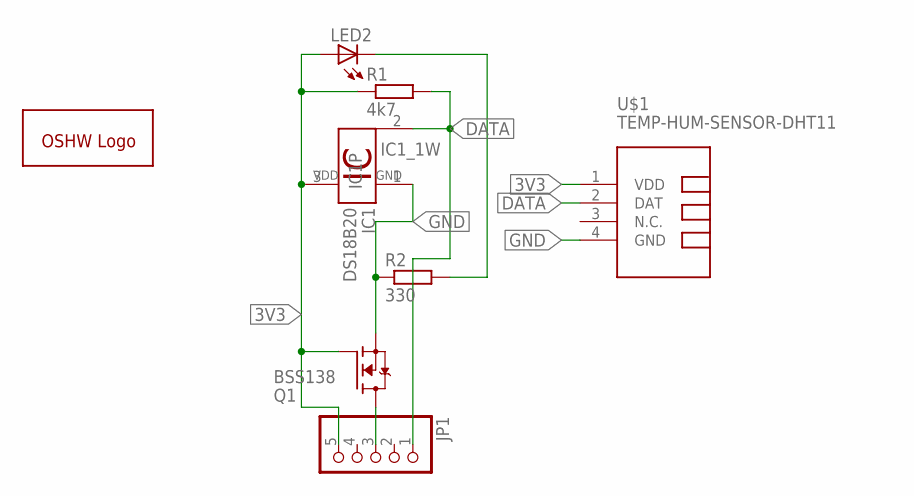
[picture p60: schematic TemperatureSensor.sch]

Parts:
IC1: DS18B20; TO92-
JP1: PINHD-1X5; 1X05
LED2: LEDSMT1206; 1206
Q1: BSS138; SOT23
R1: 4k7; R1206
R2: 330; R1206
U$1: TEMP-HUM-SENSOR-DHT11
U$2: OPENSOURCE; OSHW_5MM

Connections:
3V3: IC1.3 (VDD), JP1.5, LED2.A, Q1.1 (G), R1.1, U$1.1 (VDD)
DATA: IC1.2 (1W), JP1.1, R1.2, U$1.2 (DAT)
GND: IC1.1 (GND), Q1.2 (S), R2.1, U$1.4 (GND)
unnamed: LED2.C, R2.2
unnamed: JP1.3, Q1.3 (D)

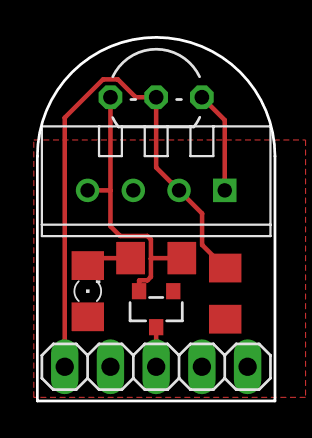
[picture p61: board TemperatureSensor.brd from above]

Board: 2 copper layers, 13.2 x 20.2 mm, 8 parts (1 on the bottom side), 5 nets.

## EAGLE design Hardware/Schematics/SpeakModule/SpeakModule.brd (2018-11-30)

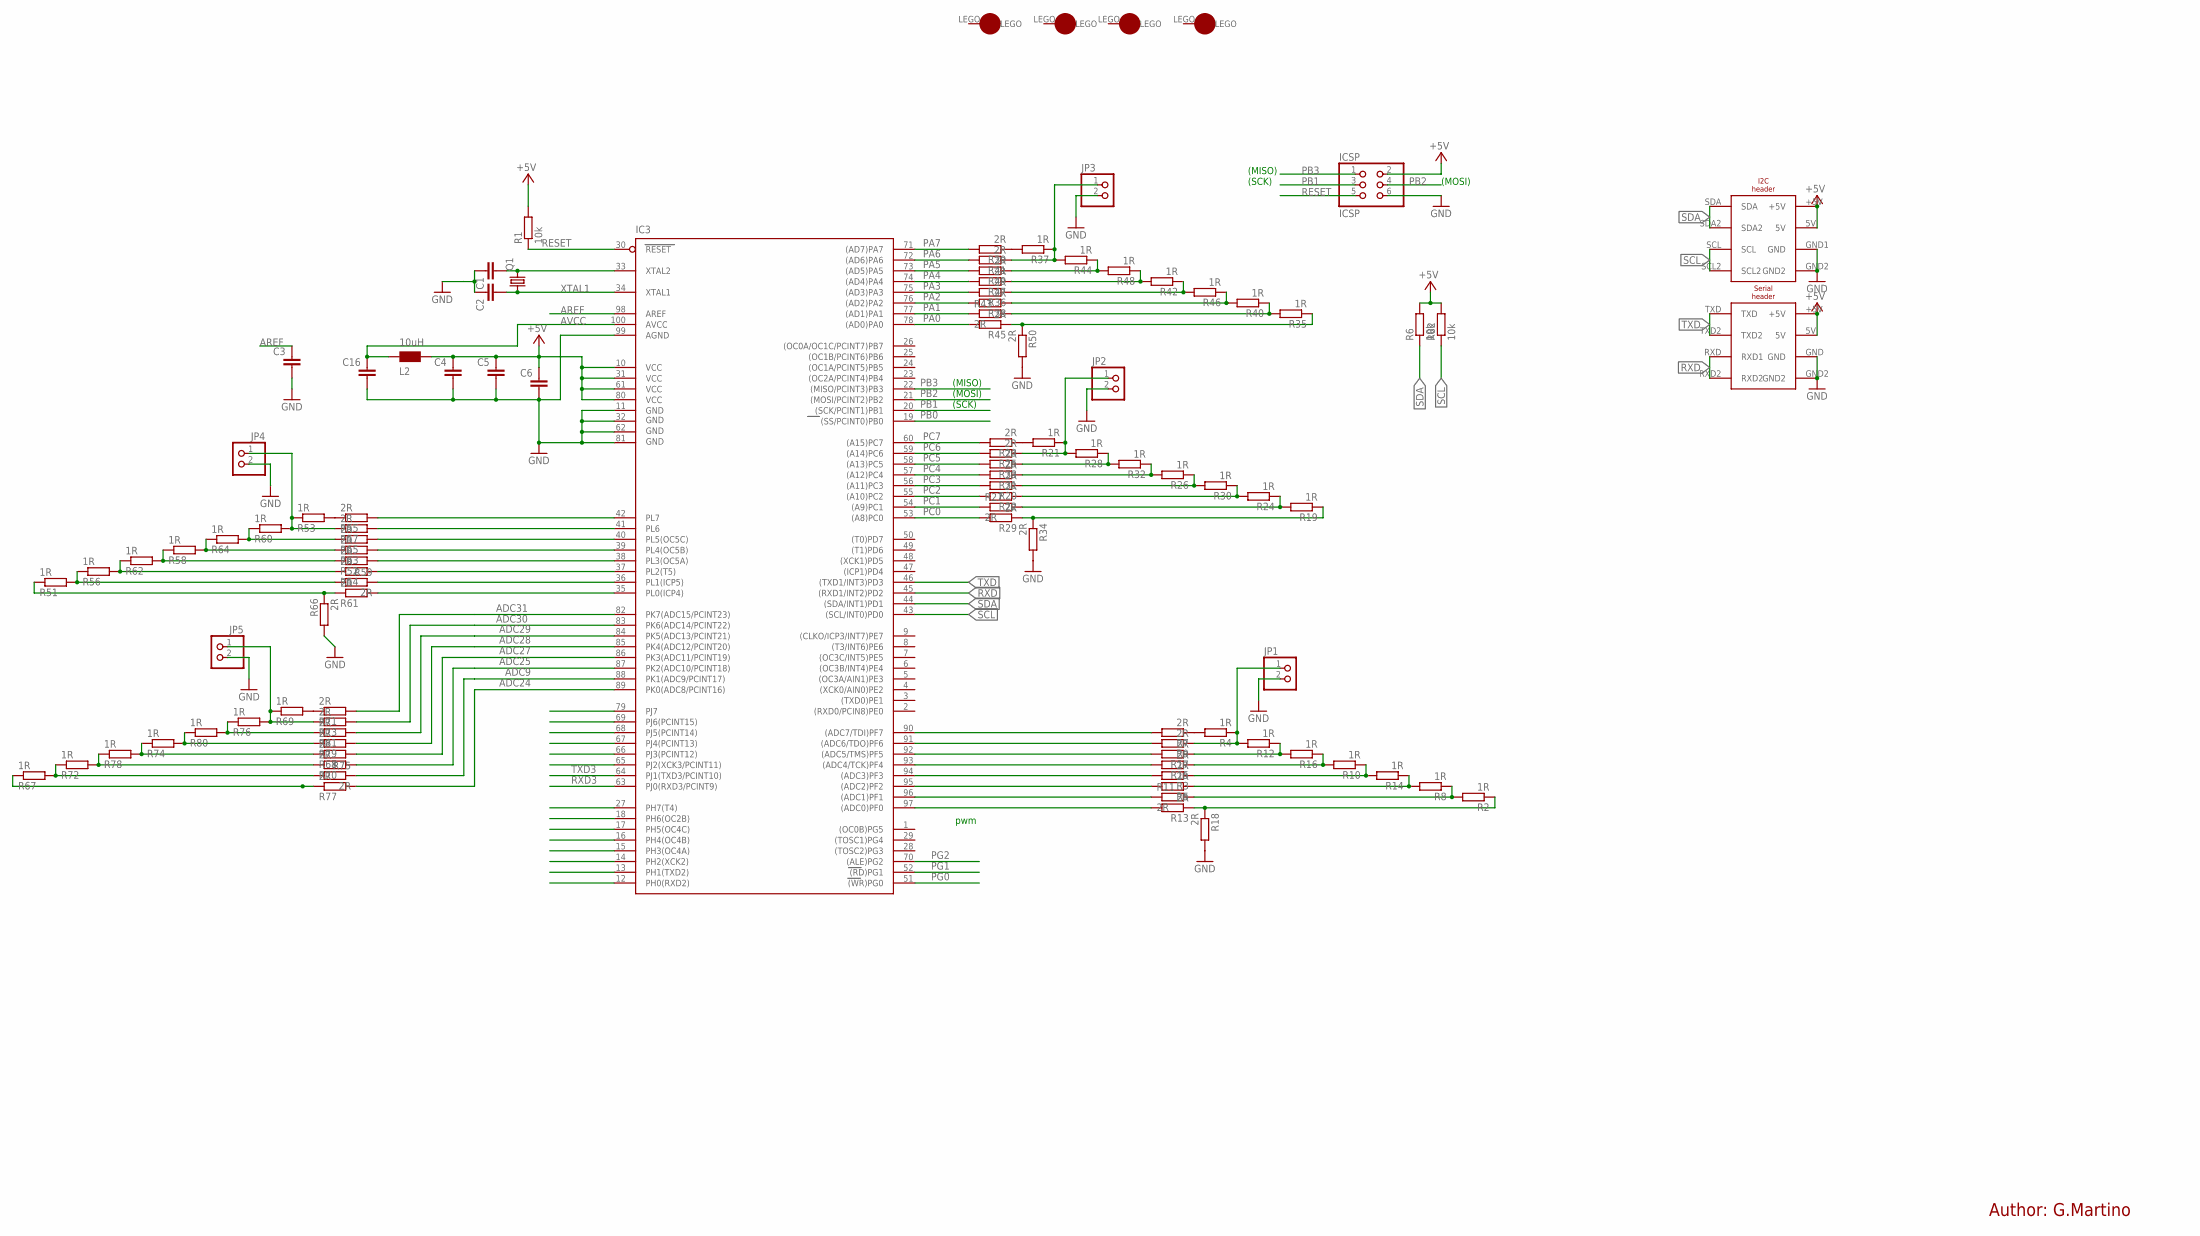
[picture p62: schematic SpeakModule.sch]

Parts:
C1, C2: 22pf; C1206
C3, C4, C5, C6, C16: 100nF; C1206
IC3: ATMEGA2560-15AU; TQFP100
ICSP: ICSP; 2X03
JP1, JP2, JP3, JP4, JP5: PINHD-1X2; 1X02
L2: 10uH; 0805
Q1: CRYSTALHC49S; HC49/S
R1, R6, R82: 10k; M1206
R2, R4, R8, R10, R12, R14, R16, R19, R21, R24, R26, R28, R30, R32, R35, R37, R40, R42, R44, R46, R48, R51, R53, R56, R58, R60, R62, R64, R67, R69, R72, R74, R76, R78, R80: 1R; M1206
R3, R5, R7, R9, R11, R13, R15, R17, R18, R20, R22, R23, R25, R27, R29, R31, R33, R34, R36, R38, R39, R41, R43, R45, R47, R49, R50, R52, R54, R55, R57, R59, R61, R63, R65, R66, R68, R70, R71, R73, R75, R77, R79, R81: 2R; M1206
U$1, U$2, U$3, U$4: LEGO-1X1
U$5: I2C_HEADER; I2_HEADER
U$6: SERIAL_HEADER

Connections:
+5V: C4.1, C5.1, C6.1, IC3.10 (VCC), IC3.31 (VCC1), IC3.61 (VCC2), IC3.80 (VCC3), ICSP.2, L2.2, R1.2, R6.2, R82.2, U$5.5V, U$5.+5V, U$6.5V, U$6.+5V
ADC0: IC3.97 ((ADC0)PF0), R13.2
ADC1: IC3.96 ((ADC1)PF1), R11.1
ADC2: IC3.95 ((ADC2)PF2), R5.2
ADC3: IC3.94 ((ADC3)PF3), R3.2
ADC4: IC3.93 ((ADC4/TCK)PF4), R15.2
ADC5: IC3.92 ((ADC5/TMS)PF5), R17.2
ADC6: IC3.91 ((ADC6/TDO)PF6), R9.2
ADC7: IC3.90 ((ADC7/TDI)PF7), R7.2
ADC9: IC3.88 (PK1(ADC9/PCINT17)), R75.1
ADC16: IC3.35 (PL0(ICP4)), R61.2
ADC17: IC3.37 (PL2(T5)), R54.2
ADC18: IC3.36 (PL1(ICP5)), R59.1
ADC19: IC3.38 (PL3(OC5A)), R52.2
ADC20: IC3.39 (PL4(OC5B)), R63.2
ADC21: IC3.40 (PL5(OC5C)), R65.2
ADC22: IC3.41 (PL6), R57.2
ADC23: IC3.42 (PL7), R55.2
ADC24: IC3.89 (PK0(ADC8/PCINT16)), R77.2
ADC25: IC3.87 (PK2(ADC10/PCINT18)), R70.2
ADC27: IC3.86 (PK3(ADC11/PCINT19)), R68.2
ADC28: IC3.85 (PK4(ADC12/PCINT20)), R79.2
ADC29: IC3.84 (PK5(ADC13/PCINT21)), R81.2
ADC30: IC3.83 (PK6(ADC14/PCINT22)), R73.2
ADC31: IC3.82 (PK7(ADC15/PCINT23)), R71.2
AREF: C3.1, IC3.98 (AREF)
AVCC: C16.1, IC3.100 (AVCC), L2.1
GND: C1.1, C2.1, C3.2, C4.2, C5.2, C6.2, C16.2, IC3.11 (GND), IC3.32 (GND1), IC3.62 (GND2), IC3.81 (GND3), IC3.99 (AGND), ICSP.6, JP1.2, JP2.2, JP3.2, JP4.2, JP5.2, R18.2, R34.2, R50.2, R66.2, U$5.GND1 (GND), U$5.GND2, U$6.GND, U$6.GND2
unnamed: C1.2, IC3.33 (XTAL2), Q1.2
unnamed: R4.2, R7.1
unnamed: JP1.1, R4.1, R9.1, R12.2
unnamed: R12.1, R16.2, R17.1
unnamed: R10.2, R15.1, R16.1
unnamed: R3.1, R10.1, R14.2
unnamed: R5.1, R8.2, R14.1
unnamed: R2.2, R8.1, R11.2
unnamed: R2.1, R13.1, R18.1
unnamed: R21.2, R23.1
unnamed: JP2.1, R21.1, R25.1, R28.2
unnamed: R28.1, R32.2, R33.1
unnamed: R26.2, R31.1, R32.1
unnamed: R20.1, R26.1, R30.2
unnamed: R22.1, R24.2, R30.1
unnamed: R19.2, R24.1, R27.2
unnamed: R19.1, R29.1, R34.1
unnamed: R37.2, R39.1
unnamed: JP3.1, R37.1, R41.1, R44.2
unnamed: R44.1, R48.2, R49.1
unnamed: R42.2, R47.1, R48.1
unnamed: R36.1, R42.1, R46.2
unnamed: R38.1, R40.2, R46.1
unnamed: R35.2, R40.1, R43.2
unnamed: R35.1, R45.1, R50.1
unnamed: R53.2, R55.1
unnamed: JP4.1, R53.1, R57.1, R60.2
unnamed: R60.1, R64.2, R65.1
unnamed: R58.2, R63.1, R64.1
unnamed: R52.1, R58.1, R62.2
unnamed: R54.1, R56.2, R62.1
unnamed: R51.2, R56.1, R59.2
unnamed: R51.1, R61.1, R66.1
unnamed: R69.2, R71.1
unnamed: JP5.1, R69.1, R73.1, R76.2
unnamed: R76.1, R80.2, R81.1
unnamed: R74.2, R79.1, R80.1
unnamed: R68.1, R74.1, R78.2
unnamed: R70.1, R72.2, R78.1
unnamed: R67.2, R72.1, R75.2
unnamed: R67.1, R77.1
PA0: IC3.78 ((AD0)PA0), R45.2
PA1: IC3.77 ((AD1)PA1), R43.1
PA2: IC3.76 ((AD2)PA2), R38.2
PA3: IC3.75 ((AD3)PA3), R36.2
PA4: IC3.74 ((AD4)PA4), R47.2
PA5: IC3.73 ((AD5)PA5), R49.2
PA6: IC3.72 ((AD6)PA6), R41.2
PA7: IC3.71 ((AD7)PA7), R39.2
PB0: IC3.19 ((SS/PCINT0)PB0)
PB1: IC3.20 ((SCK/PCINT1)PB1), ICSP.3
PB2: IC3.21 ((MOSI/PCINT2)PB2), ICSP.4
PB3: IC3.22 ((MISO/PCINT3)PB3), ICSP.1
PC0: IC3.53 ((A8)PC0), R29.2
PC1: IC3.54 ((A9)PC1), R27.1
PC2: IC3.55 ((A10)PC2), R22.2
PC3: IC3.56 ((A11)PC3), R20.2
PC4: IC3.57 ((A12)PC4), R31.2
PC5: IC3.58 ((A13)PC5), R33.2
PC6: IC3.59 ((A14)PC6), R25.2
PC7: IC3.60 ((A15)PC7), R23.2
PG0: IC3.51 ((WR)PG0)
PG1: IC3.52 ((RD)PG1)
PG2: IC3.70 ((ALE)PG2)
RESET: IC3.30 (RESET), ICSP.5, R1.1
RXD: IC3.45 ((RXD1/INT2)PD2), U$6.RXD (RXD1), U$6.RXD2
RXD3: IC3.63 (PJ0(RXD3/PCINT9))
SCL: IC3.43 ((SCL/INT0)PD0), R82.1, U$5.SCL, U$5.SCL2
SDA: IC3.44 ((SDA/INT1)PD1), R6.1, U$5.SDA, U$5.SDA2
TXD: IC3.46 ((TXD1/INT3)PD3), U$6.TXD, U$6.TXD2
TXD3: IC3.64 (PJ1(TXD3/PCINT10))
XTAL1: C2.2, IC3.34 (XTAL1), Q1.1

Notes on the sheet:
(SCK)
(MISO)
(MOSI)
pwm
Author: G.Martino

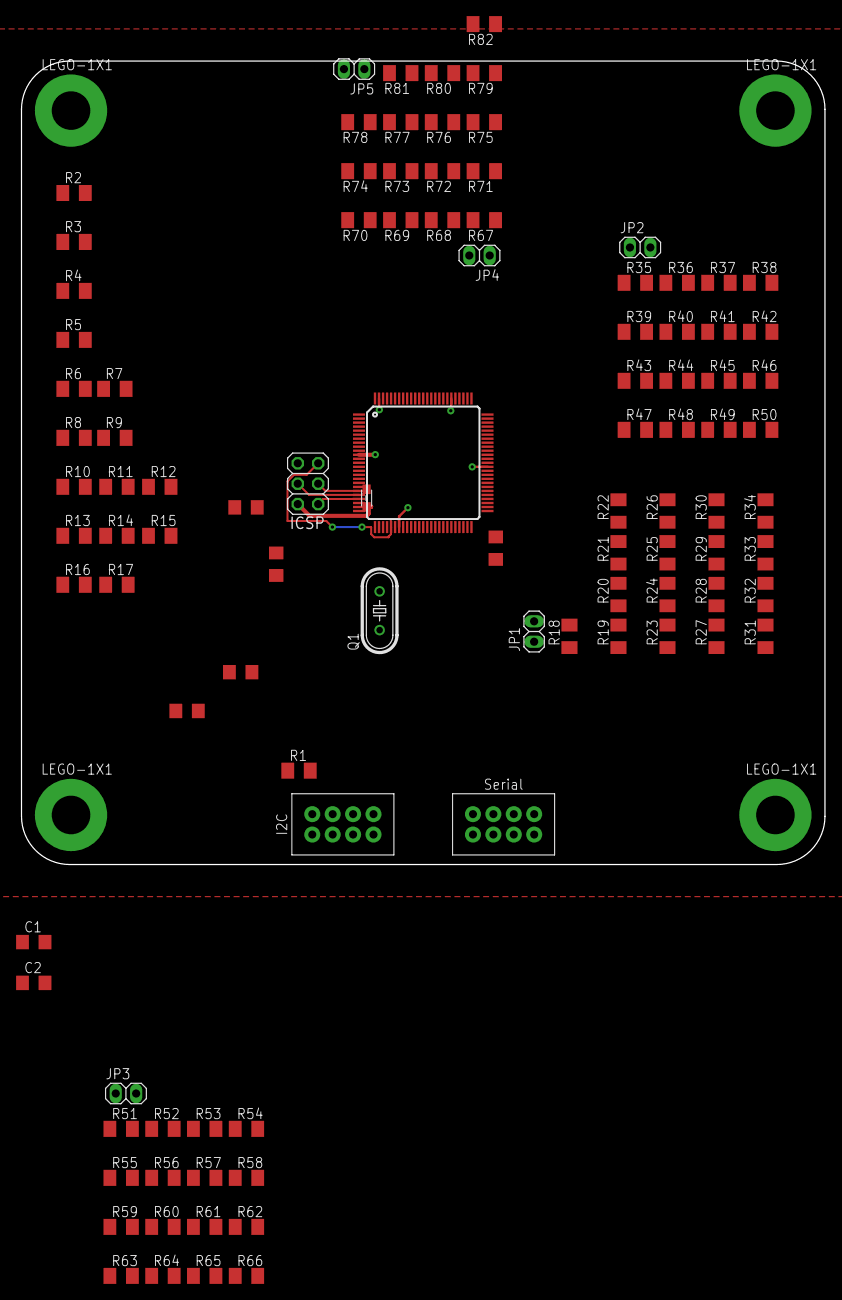
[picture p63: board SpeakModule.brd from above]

Board: 2 copper layers, 100.0 x 100.0 mm, 104 parts (0 on the bottom side), 94 nets.

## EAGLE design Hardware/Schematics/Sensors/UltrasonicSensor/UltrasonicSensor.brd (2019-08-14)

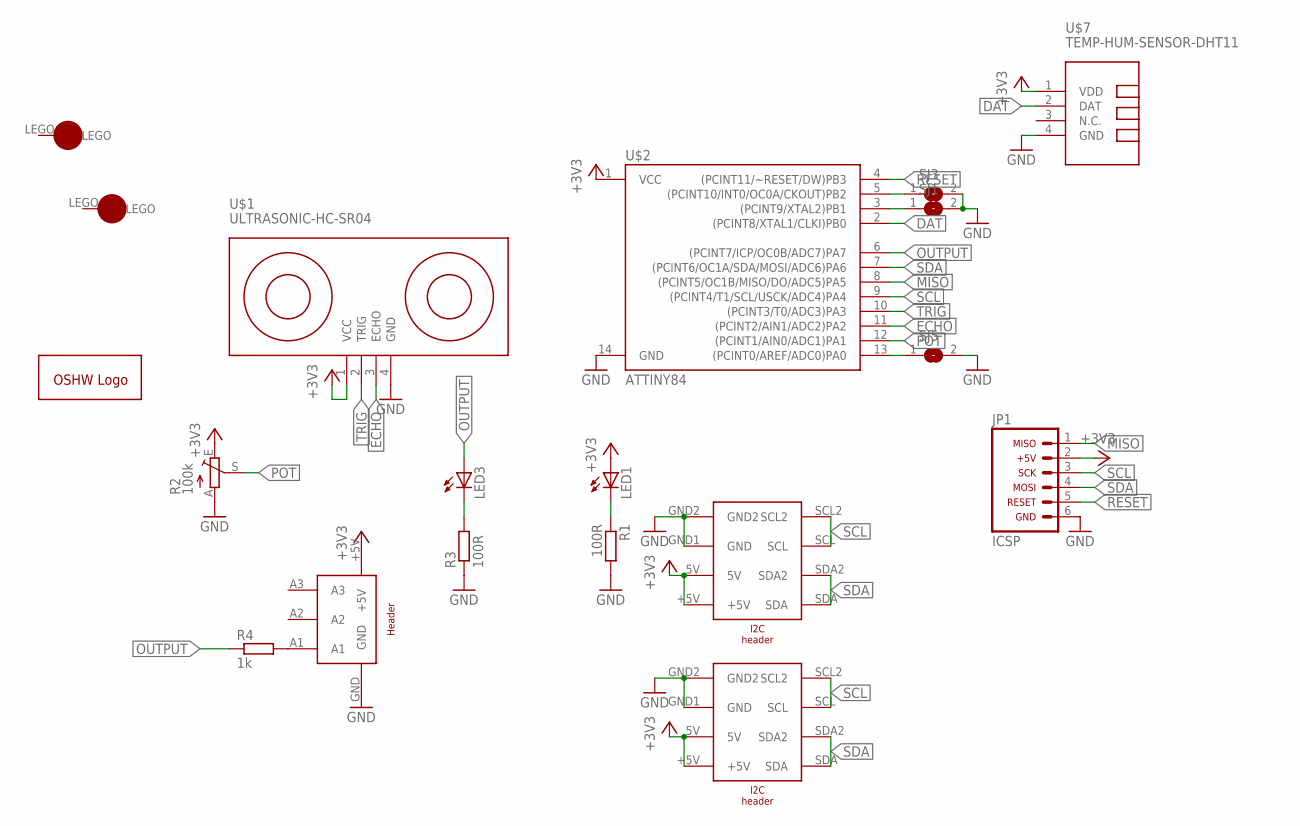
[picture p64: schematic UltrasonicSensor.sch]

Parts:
JP1: ICSP_HEADER
LED1, LED3: LEDCHIPLED_1206; CHIPLED_1206
R1, R3: 100R; M1206
R2: 100k; B64Y
R4: 1k; M1206
SJ1, SJ3, SJ5: SJ
U$1: ULTRASONIC-HC-SR04
U$2: ATTINY84; SO14
U$3, U$4: I2C_HEADER; I2_HEADER
U$5: OPENSOURCE; OSHW_5MM
U$6: CONNECTOR_1X5
U$7: TEMP-HUM-SENSOR-DHT11
U$8, U$9: LEGO-1X1

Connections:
0: SJ5.1, U$2.13 ((PCINT0/AREF/ADC0)PA0)
8: SJ3.1, U$2.5 ((PCINT10/INT0/OC0A/CKOUT)PB2)
9: SJ1.1, U$2.3 ((PCINT9/XTAL2)PB1)
+3V3: JP1.2, LED1.A, R2.E, U$1.1 (VCC), U$2.1 (VCC), U$3.5V, U$3.+5V, U$4.5V, U$4.+5V, U$6.+5V, U$7.1 (VDD)
DAT: U$2.2 ((PCINT8/XTAL1/CLKI)PB0), U$7.2 (DAT)
ECHO: U$1.3 (ECHO), U$2.11 ((PCINT2/AIN1/ADC2)PA2)
GND: JP1.6, R1.2, R2.A, R3.1, SJ1.2, SJ3.2, SJ5.2, U$1.4 (GND), U$2.14 (GND), U$3.GND1 (GND), U$3.GND2, U$4.GND1 (GND), U$4.GND2, U$6.GND, U$7.4 (GND)
MISO: JP1.1, U$2.8 ((PCINT5/OC1B/MISO/DO/ADC5)PA5)
unnamed: R4.2, U$6.A1
unnamed: LED1.C, R1.1
unnamed: LED3.C, R3.2
OUTPUT: LED3.A, R4.1, U$2.6 ((PCINT7/ICP/OC0B/ADC7)PA7)
POT: R2.S, U$2.12 ((PCINT1/AIN0/ADC1)PA1)
RESET: JP1.5, U$2.4 ((PCINT11/~RESET/DW)PB3)
SCL: JP1.3, U$2.9 ((PCINT4/T1/SCL/USCK/ADC4)PA4), U$3.SCL, U$3.SCL2, U$4.SCL, U$4.SCL2
SDA: JP1.4, U$2.7 ((PCINT6/OC1A/SDA/MOSI/ADC6)PA6), U$3.SDA, U$3.SDA2, U$4.SDA, U$4.SDA2
TRIG: U$1.2 (TRIG), U$2.10 ((PCINT3/T0/ADC3)PA3)

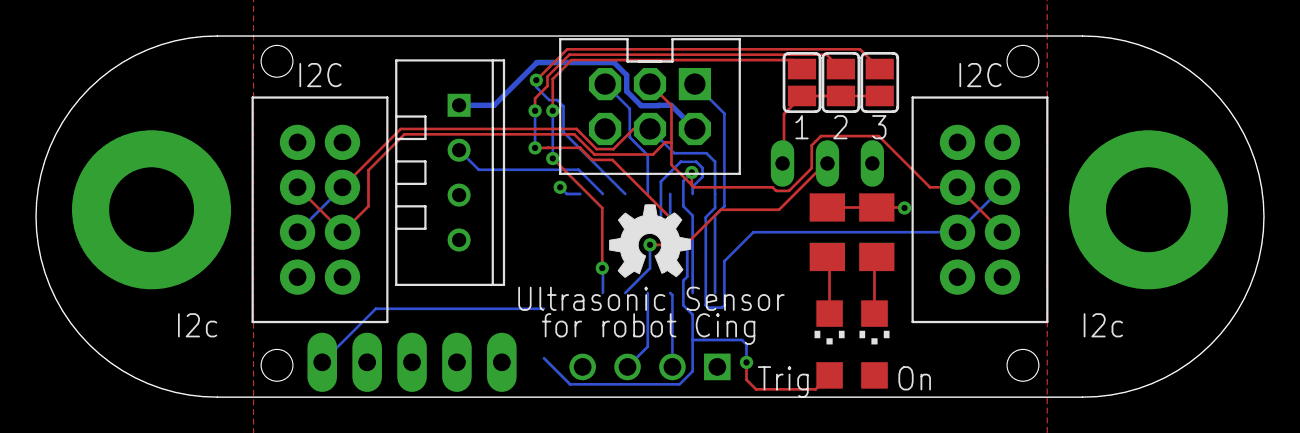
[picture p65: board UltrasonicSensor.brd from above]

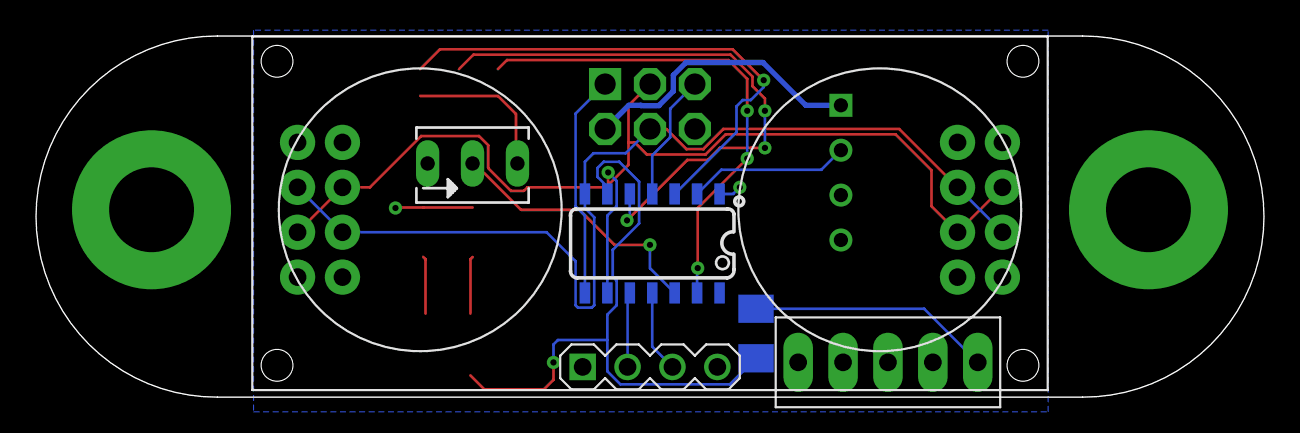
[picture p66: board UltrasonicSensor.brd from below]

Board: 2 copper layers, 69.5 x 20.4 mm, 19 parts (5 on the bottom side), 17 nets.

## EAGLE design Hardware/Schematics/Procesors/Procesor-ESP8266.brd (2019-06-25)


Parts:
J1, J2, J3, J4: CONN_08SMD-STRAIGHT-ALT-FEMALE; 1X08_SMD_ALT
JP5: PINHD-1X1; 1X01
TP1: PTR1B1,27; B1,27
U1: ESP12ESMD; ESP12E-SMD

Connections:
+5V: J2.4, J2.6, J4.2, U1.CH_PD, U1.GPIO2, U1.VCC
A0: J4.7, U1.GPIO10 (*GPIO10)
A2: J1.1, U1.SCLK
A3: J1.2, U1.MOSI
A4: J1.3, U1.GPIO4
A5: J1.4, U1.GPIO5
A6: J4.3, TP1.TP, U1.GPIO0
D3: J2.1, U1.GPIO9 (*GPIO9)
GND: J2.3, J2.5, J4.5, U1.GND, U1.GPIO15
INA1: J3.6, U1.GPIO13
INA2: J3.5, U1.GPIO16
INB1: J3.4, U1.CS0
INB2: J3.3, U1.MISO
MISO: J3.8, U1.GPIO14
MOSI: J3.7, U1.GPIO12
RESET: J1.5, U1.RESET
RXD: J1.6, U1.RXD0 (RX)
SCK: J4.1, U1.ADC
TXD: J1.7, U1.TXD0 (TX)



Board: 2 copper layers, 34.0 x 34.0 mm, 7 parts (4 on the bottom side), 19 nets.

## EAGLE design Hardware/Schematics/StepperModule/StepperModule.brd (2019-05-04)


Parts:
C1, C2: CPOL-EUTT5D9; TT5D9
IC1: L293D; L293
JP1, JP2, JP4, JP5: PINHD-1X8; 1X08
JP3, JP6: PINHD-1X4; 1X04
LED1, LED2: LEDSML1206; SML1206
R1, R2: R-EU_M1206; M1206
U$5: OPENSOURCE; OSHW_5MM

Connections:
+3V3: IC1.16 (VCC1), JP1.2, JP1.3, JP1.4, JP2.2, JP4.2, JP4.3, JP4.4, JP5.2, R1.1
+12V: C1.+, C2.+, IC1.8 (VCC2), JP2.8, JP5.8, R2.1
DIRA: IC1.15 (4A), JP1.8
DIRB: IC1.7 (2A), JP4.8
ENA: IC1.9 (3-4EN), JP1.1
ENB: IC1.1 (1-2EN), JP4.1
GND: C1.-, C2.-, IC1.4 (GND1), IC1.5 (GND2), IC1.12 (GND4), IC1.13 (GND3), JP2.1, JP2.7, JP5.1, JP5.7, LED1.C, LED2.C
unnamed: LED1.A, R1.2
unnamed: LED2.A, R2.2
unnamed: JP4.5, JP4.6
unnamed: JP1.5, JP1.6
unnamed: JP5.3, JP6.4
unnamed: JP5.4, JP6.3
unnamed: JP2.3, JP3.4
unnamed: JP2.4, JP3.3
unnamed: JP2.5, JP3.2
unnamed: JP2.6, JP3.1
unnamed: JP5.5, JP6.2
unnamed: JP5.6, JP6.1
STEPA: IC1.10 (3A), JP1.7
STEPB: IC1.2 (1A), JP4.7


Board: 2 copper layers, 53.0 x 25.5 mm, 14 parts (1 on the bottom side), 21 nets.

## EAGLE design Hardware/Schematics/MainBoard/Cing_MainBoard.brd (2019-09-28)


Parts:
C7, C8: 22p; C1206
C11, C12, C13, C25, C26: 100n; C1206
Q1: 16mhz; HC49U
R1, R2: 10k; R1206
S2: Reset; B3F-10XX
S4: Button; B3F-10XX
U$1: PROCESSOR-SOCKET_PCB

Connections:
36: U$1.36; also elsewhere on the board
+3V3: C11.2, C12.1, C13.1, C26.2, R1.2, S4.2 (S1), U$1.VCC, U$1.VCC2, U$1.VCC3; also elsewhere on the board
A0: U$1.A0; also elsewhere on the board
A1: U$1.A1; also elsewhere on the board
A2: U$1.A2; also elsewhere on the board
A3: U$1.A3; also elsewhere on the board
A6: U$1.A6; also elsewhere on the board
A7: U$1.A7; also elsewhere on the board
ATMEGA_D+: U$1.D+; also elsewhere on the board
ATMEGA_D-: U$1.D-; also elsewhere on the board
BUTTON: C26.1, R2.2, S4.4 (P1); also elsewhere on the board
D2: U$1.D2; also elsewhere on the board
D3: U$1.D3; also elsewhere on the board
D4: U$1.D4; also elsewhere on the board
D5: U$1.D5; also elsewhere on the board
D6: U$1.D6; also elsewhere on the board
GND: C7.1, C8.1, C11.1, C12.2, C13.2, C25.1, R2.1, S2.4 (P1), U$1.GND, U$1.GND2, U$1.GND3; also elsewhere on the board
IN_A1: U$1.D10; also elsewhere on the board
IN_A2: U$1.D9; also elsewhere on the board
IN_B1: U$1.D8; also elsewhere on the board
IN_B2: U$1.D7; also elsewhere on the board
MISO: U$1.D12; also elsewhere on the board
MOSI: U$1.D11; also elsewhere on the board
unnamed: C8.2, Q1.3, U$1.CRYST2
unnamed: C7.2, Q1.1, U$1.CRYST1
RESET: C25.2, R1.1, S2.2 (S1), U$1.RESET; also elsewhere on the board
RXD: U$1.D0; also elsewhere on the board
SCK: U$1.D13; also elsewhere on the board
SCL: U$1.A5; also elsewhere on the board
SDA: U$1.A4; also elsewhere on the board
TXD: U$1.D1; also elsewhere on the board

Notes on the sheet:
Procesor Socket

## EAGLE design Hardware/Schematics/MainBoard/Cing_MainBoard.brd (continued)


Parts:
JP5: ICSP; ICSP_HEADER
JP23: PINHD-1X2; 1X02
MOT_A: MKDSN1,5/2-5,08
MOT_B: MKDSN1,5/2-5,08
Q2, Q3, Q4, Q5: BSS138; SOT23
R33, R34, R35, R37, R38, R39, R40: 10k; R1206
R36: 100; R1206
R44: 100R; R1206
SW4: USB_SWITCH
U$2: Header 2; BIG_HEADER
U$3: I2C_HEADER; I2_HEADER
U$4: SERIAL_HEADER
U$9, U$24: POLULU_MOTOR
U$16: BAT+; LEGO-1X1
U$17: 3.3V; LEGO-1X1
U$18, U$19: GND; LEGO-1X1
U$20: BALL
U$22: OPENSOURCE; OSHW_5MM
VERSION: 4.1; VERSION

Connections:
36: U$2.+5V1; also elsewhere on the board
+3V3: Q2.1 (G), Q3.1 (G), Q4.1 (G), Q5.1 (G), R34.1, R38.1, R40.1, U$2.+3V3, U$3.5V, U$3.+5V, U$4.5V, U$4.+5V, U$17.LEGO; also elsewhere on the board
+5V: JP5.2, R33.1, R35.1, R36.1, R37.1, R39.1, R44.1
A0H: U$2.A0; also elsewhere on the board
A1: U$2.A1; also elsewhere on the board
A6: SW4.COM1; also elsewhere on the board
A7: U$2.A7; also elsewhere on the board
BAT+: U$2.+5V, U$16.LEGO; also elsewhere on the board
BUTTON: SW4.CH1B; also elsewhere on the board
D2: U$2.D2; also elsewhere on the board
D3: U$2.D3; also elsewhere on the board
D4: U$2.D4; also elsewhere on the board
D5: U$2.D5; also elsewhere on the board
D6: U$2.D6; also elsewhere on the board
GND: JP5.6, U$2.GND, U$2.GND2 (GND1), U$3.GND1 (GND), U$3.GND2, U$4.GND, U$4.GND2, U$18.LEGO, U$19.LEGO; also elsewhere on the board
HD_A6: SW4.CH1A, U$2.A6
MISO: Q4.2 (S), R38.2; also elsewhere on the board
MISO_HV: JP5.1, Q4.3 (D), R37.2
MOSI: Q2.2 (S), R34.2; also elsewhere on the board
MOSI_HV: JP5.4, Q2.3 (D), R33.2
MOT_A+: MOT_A.2, U$24.+; also elsewhere on the board
MOT_A-: MOT_A.1, U$24.-; also elsewhere on the board
MOT_B+: MOT_B.2, U$9.+; also elsewhere on the board
MOT_B-: MOT_B.1, U$9.-; also elsewhere on the board
RESET: Q3.2 (S); also elsewhere on the board
RESET_HV: JP5.5, Q3.3 (D), R35.2
RXD: U$2.D0, U$4.RXD (RXD1), U$4.RXD2; also elsewhere on the board
SCK: Q5.2 (S), R40.2; also elsewhere on the board
SCK_HV: JP5.3, Q5.3 (D), R39.2
SCL: JP23.2, U$2.A5, U$3.SCL, U$3.SCL2; also elsewhere on the board
SDA: JP23.1, U$2.A4, U$3.SDA, U$3.SDA2; also elsewhere on the board
TXD: U$2.D1, U$4.TXD, U$4.TXD2; also elsewhere on the board
VCC_SERVO: R36.2, R44.2; also elsewhere on the board

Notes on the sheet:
Headers


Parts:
IC1: L293D; L293
JP2: ServoA; 1X03
JP3: ServoB; 1X03
JP4: ServoC; 1X03
R12, R13, R14, R15: 10k; R1206
SW6: USB_SWITCH

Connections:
+3V3: IC1.16 (VCC1), R13.2, R14.1; also elsewhere on the board
D6: JP4.1; also elsewhere on the board
GND: IC1.4 (GND1), IC1.5 (GND2), IC1.12 (GND4), IC1.13 (GND3), JP2.3, JP3.3, JP4.3, R12.2, R15.1; also elsewhere on the board
IN_A1: IC1.2 (1A), JP3.1, R14.2; also elsewhere on the board
IN_A2: IC1.7 (2A), JP2.1, R15.2; also elsewhere on the board
IN_B1: IC1.15 (4A), R13.1; also elsewhere on the board
IN_B2: IC1.10 (3A), R12.1; also elsewhere on the board
MISO: IC1.1 (1-2EN); also elsewhere on the board
MOSI: IC1.9 (3-4EN); also elsewhere on the board
MOT_A+: IC1.3 (1Y); also elsewhere on the board
MOT_A-: IC1.6 (2Y); also elsewhere on the board
MOT_B+: IC1.14 (4Y); also elsewhere on the board
MOT_B-: IC1.11 (3Y); also elsewhere on the board
unnamed: IC1.8 (VCC2), SW6.CH1A, SW6.CH2A
VCC_MOT: SW6.COM1, SW6.COM2; also elsewhere on the board
VCC_SERVO: JP2.2, JP3.2, JP4.2; also elsewhere on the board

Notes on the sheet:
L293 motor driver


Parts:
1, 8205: FS8205; TSSOP-8
BT1: BATTERY-AA_KIT; BATTERY-AA-KIT
C1, C5, C9, C10, C16, C24: 100n; C1206
C4, C14, C15: 22uf; C1206
C17, C23: 47uf; 153CLV-0505
C27: 10uf; 153CLV-0505
D1, D3: DIODESMA; SMADIODE
IC2: LM2576S; TO263-5
L1: DR125
L2: DR127
LED1: Charging; 1206
ON: GREEN; 1206
Q6, Q7: NP2301AMR-G; SOT23
R3: 40; R1206
R4, R8, R46, R47: 1k; R1206
R5, R9, R11: 10k; R1206
R6, R22: R100; R1206
R41: 2R; R1206
R48: 100; R1206
R49: 12K; R1206
REV: RED; 1206
SJ1: SJW
SJ2: SJ
SW1, SW5: USB_SWITCH
T1, T2: FS8205; TSSOP-8
TP4056: TP4056
U1: MICRO_USB""; USB-MICRO-SMD
U$5: MT3608SOT23-6; SOT23-6
U$6, U$7: BATTERY_CONECTOR_D
U$8: DW01; SOT23-6
U$13: ADS1015IDGT; MSOP10_0.5
U$25, U$26: LM39100S-3.3
YELLOW: Full; 1206

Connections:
+3V3: C5.1, C10.1, U$25.3 (VO), U$26.3 (VO); also elsewhere on the board
ATMEGA_D+: SW1.CH2A; also elsewhere on the board
ATMEGA_D-: SW1.CH1A; also elsewhere on the board
BAT+: C15.1, L1.1, R41.1, R48.2, U$5.P$4 (EN), U$5.P$5 (IN), U$13.4 (AIN0), U$13.7 (AIN3), U$25.1 (VI), U$26.1 (VI); also elsewhere on the board
BAT-: 1.2 (S), 1.3 (S), 8205.2 (S), 8205.3 (S), BT1.GND@1 (-), C16.2, C27.-, ON.C, Q6.1 (G), Q7.1 (G), R6.1, T1.2 (S), T1.3 (S), T2.2 (S), T2.3 (S), U$7.-, U$8.6 (GND)
CUR-SENSE: R22.1, R41.2, SW5.CH1B, SW5.CH2B, U$13.6 (AIN2)
D+: SW1.CH2B; also elsewhere on the board
D-: SW1.CH1B; also elsewhere on the board
GND: 1.6 (S), 1.7 (S), 8205.6 (S), 8205.7 (S), C1.2, C4.2, C5.2, C9.2, C10.2, C14.2, C15.2, C17.-, C23.-, C24.2, D1.A, IC2.3 (GND), R8.2, R46.2, R47.2, T1.6 (S), T1.7 (S), T2.6 (S), T2.7 (S), TP4056.1 (TEMP), TP4056.3 (GND), U1.GND1 (GND), U1.ID1 (USBID), U$5.P$2 (GND), U$6.-, U$13.1 (ADDR), U$13.3 (GND), U$13.5 (AIN1), U$25.2 (GND), U$25.TAB (GND_2), U$26.2 (GND), U$26.TAB (GND_2); also elsewhere on the board
IRFU: BT1.PWR@1 (+), C1.1, Q6.3 (D), Q7.3 (D), REV.C, SJ2.1, U$7.+
unnamed: 1.1 (D), 1.8 (D)
unnamed: R6.2, REV.A
unnamed: R4.2, R8.1
unnamed: SW1.COM1, U1.D-1 (D-)
unnamed: LED1.C, R5.1
unnamed: SW1.COM2, U1.D+1 (D+)
unnamed: R11.1, YELLOW.C
unnamed: R11.2, TP4056.6 (STDBY)
unnamed: R5.2, TP4056.7 (CHRG)
unnamed: D1.C, IC2.2 (OUT), L2.1
unnamed: LED1.A, R3.2, TP4056.4 (VCC), TP4056.8 (CE), YELLOW.A
unnamed: C27.+, Q6.2 (S), Q7.2 (S), SJ2.2, SW5.COM1, SW5.COM2, TP4056.5 (BAT)
unnamed: R4.1, TP4056.2 (PROG)
unnamed: ON.A, R22.2
unnamed: R9.2, R46.1, R49.2, U$5.P$3 (FB)
unnamed: D3.A, L1.2, U$5.P$1 (SW)
unnamed: C14.1, D3.C, R9.1, R49.1, SJ1.1
unnamed: 8205.1 (D), 8205.8 (D)
unnamed: 1.4 (G), 8205.4 (G), T1.4 (G), T2.4 (G), U$8.1 (0D)
unnamed: 1.5 (G), 8205.5 (G), T1.5 (G), T2.5 (G), U$8.3 (0C)
unnamed: C16.1, R48.1, U$8.5 (VCC)
unnamed: R47.1, U$8.2 (CS)
unnamed: T1.1 (D), T1.8 (D)
unnamed: T2.1 (D), T2.8 (D)
SCL: U$13.10 (SCL); also elsewhere on the board
SDA: U$13.9 (SDA); also elsewhere on the board
VCC_MOT: C23.+, C24.1, IC2.1 (VIN), SJ1.2, U$6.+; also elsewhere on the board
VCC_SERVO: C4.1, C9.1, C17.+, IC2.4 (FB), L2.2, U$13.8 (VDD); also elsewhere on the board
VUSB: R3.1, U1.VBUS1 (VBUS); also elsewhere on the board

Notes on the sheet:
Power managment


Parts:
C2, C3, C6, C18, C21, C28, C29, C30, C31: 100n; C1206
C22: 22uf; C1206
IC3: FT232RL
IC4: BMP280
IC5: BME280
JP21, JP22: PINHD-1X1; 1X01
LED3: RXD; 1206
LS1: 1; TCRT5000
LS2: 2; TCRT5000
POT: 100k; RJ9W
R10, R20: 4k7; R1206
R16, R18, R24, R25: 100; R1206
R17, R19: 10k; R1206
R21, R23: PHOTOCELL1; LDR_OFFBOARD
R26: 40; R1206
R27, R28, R29, R30, R31, R32: 1k; R1206
SW2, SW3, SW7: USB_SWITCH
TSOP4838: TSOP4838; TSOP18XX
TXD: TXD; 1206
TXD1: LightSensor 1; 1206
TXD2: LightSensor 2; 1206
U3: MPU-6050MPU6050; MPU-6050
U4: CH330N; SOIC-8N
U$12: CONNECTOR_1X5

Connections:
+3V3: C6.2, C21.2, C22.1, C28.1, C29.2, C30.2, C31.2, IC4.2 (CSB), IC4.5 (SDO), IC4.6 (VDDIO), IC4.8 (VDD), IC5.2 (CSB), IC5.6 (VDDIO), IC5.8 (VDD), JP21.1, JP22.1, POT.E, R10.2, R16.1, R17.1, R18.1, R19.1, R20.2, R29.2, R30.2, R31.2, R32.2, TSOP4838.VCC (V+), U3.VCC, U4.5 (VCC), U4.8 (V3), U$12.+5V; also elsewhere on the board
A0: SW7.COM1; also elsewhere on the board
A0H: SW7.CH1B; also elsewhere on the board
A1: POT.S; also elsewhere on the board
A2: R27.1; also elsewhere on the board
A3: R28.2; also elsewhere on the board
A7: R21.2, R32.1; also elsewhere on the board
D4: TSOP4838.OUT; also elsewhere on the board
D+: IC3.15 (USBDP), U4.1 (USB_D+); also elsewhere on the board
D-: IC3.16 (USBDM), U4.2 (USB_D-); also elsewhere on the board
GND: C2.2, C6.1, C21.1, C22.2, C28.2, C29.1, C30.1, C31.1, IC3.7 (GND), IC3.18 (GND), IC3.21 (GND), IC3.25 (AGND), IC3.26 (TEST), IC4.1 (GND), IC4.7 (GND), IC5.1 (GND), IC5.5 (SDO), IC5.7 (GND), LS1.E (EMITTER), LS1.K (CATHODE), LS2.E (EMITTER), LS2.K (CATHODE), POT.A, R21.1, R23.1, TSOP4838.GND, U3.GND, U4.3 (GND), U$12.GND; also elsewhere on the board
unnamed: R28.1, SW2.COM1
unnamed: R10.1, TXD1.A
unnamed: R20.1, TXD2.A
unnamed: LS2.A (ANODE), R16.2
unnamed: LS1.A (ANODE), R18.2
unnamed: LS1.C (COLLECTOR), R19.2, SW3.CH1B, TXD1.C
unnamed: SW3.CH1A, U$12.A2
unnamed: LED3.A, R24.2
unnamed: IC3.22 (CBUS1), LED3.C
unnamed: R25.2, TXD.A
unnamed: C3.1, IC3.2 (_DTR)
unnamed: C2.1, IC3.4 (VCCIO), IC3.17 (3V3OUT), R24.1, R25.1
unnamed: SW2.CH1B, U$12.A3
unnamed: R26.2, U$12.A1
unnamed: R27.2, SW3.COM1
unnamed: LS2.C (COLLECTOR), R17.2, SW2.CH1A, TXD2.C
unnamed: C18.2, IC3.3 (_RTS)
unnamed: R23.2, R29.1, SW7.CH1A
RESET: C3.2, C18.1; also elsewhere on the board
RXD: IC3.1 (TXD), U4.6 (TXD); also elsewhere on the board
SCK: R26.1; also elsewhere on the board
SCL: IC4.4 (SCK), IC5.4 (SCK), R30.1, U3.SCL; also elsewhere on the board
SDA: IC4.3 (SDI), IC5.3 (SDI), R31.1, U3.SDA; also elsewhere on the board
T: IC3.23 (CBUS0), TXD.C
TXD: IC3.5 (RXD), U4.7 (RXD); also elsewhere on the board
VUSB: IC3.20 (VCC); also elsewhere on the board


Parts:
C19, C20: 100n; C1206
JP1, JP6, JP7, JP8, JP9, JP10, JP11, JP12, JP13, JP14, JP15, JP16, JP17, JP18, JP19, JP20: PINHD-1X1; 1X01
LED4, LED9, LED10, LED11: WS2812B3535; LED3535
LED5, LED6, LED7, LED8: WS2812B
R7, R42, R43: 10k; R1206
U2: SX1509; QFN-28
U$14: RANGING-SENSOR-VL53L0X
U$15: COMPASS-HMC5883L
U$23: WIRELESS-BLUETOOTH-HC-05
WS2812: PINHD-1X3; 1X03

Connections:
+3V3: C19.1, C20.1, R42.1, R43.2, U2.4 (VCC1), U2.12 (VDDM), U2.18 (VCC2), U$15.1 (VCC); also elsewhere on the board
D2: U$23.3 (TX); also elsewhere on the board
D5: U$23.2 (RX); also elsewhere on the board
GND: C19.2, C20.2, LED4.4 (GND), LED5.3 (VSS), LED6.3 (VSS), LED7.3 (VSS), LED8.3 (VSS), LED9.4 (GND), LED10.4 (GND), LED11.4 (GND), U2.3 (GND), U2.10 (ADDR1), U2.17 (GND), U2.26 (ADDR0), U2.29 (GND), U$14.2 (GND), U$15.2 (GND), U$23.4 (GND), WS2812.3; also elsewhere on the board
unnamed: LED5.2 (DO), LED6.4 (DI), LED9.1 (DI), LED10.3 (DO)
unnamed: LED4.1 (DI), LED6.2 (DO), LED7.4 (DI), LED9.3 (DO)
unnamed: LED4.3 (DO), LED7.2 (DO), LED8.4 (DI), LED11.1 (DI)
unnamed: LED5.4 (DI), LED10.1 (DI), R7.1
unnamed: R42.2, U2.9 (!INT)
unnamed: R43.1, U2.23 (!RESET)
unnamed: JP1.1, U2.7 (I/O[6])
unnamed: JP6.1, U2.6 (I/O[5])
unnamed: JP7.1, U2.5 (I/O[4])
unnamed: LED8.2 (DO), LED11.3 (DO), WS2812.2
unnamed: JP8.1, U2.1 (I/O[2])
unnamed: JP9.1, U2.2 (I/O[3])
unnamed: JP10.1, U2.28 (I/O[1])
unnamed: JP11.1, U2.27 (I/O[0])
unnamed: JP12.1, U2.21 (I/O[14])
unnamed: JP13.1, U2.20 (I/O[13])
unnamed: JP14.1, U2.19 (I/O[12])
unnamed: JP15.1, U2.15 (I/O[10])
unnamed: JP16.1, U2.14 (I/O[9])
unnamed: JP17.1, U2.13 (I/O[8])
unnamed: JP18.1, U2.8 (I/O[7])
unnamed: JP19.1, U2.16 (I/O[11])
unnamed: JP20.1, U2.22 (I/O[15])
SCK: R7.2; also elsewhere on the board
SCL: U2.25 (SCL), U$14.3 (SCL), U$15.3 (SCL); also elsewhere on the board
SDA: U2.24 (SDA), U$14.4 (SDA), U$15.4 (SDA); also elsewhere on the board
VCC_SERVO: LED4.2 (VDD), LED5.1 (VDD), LED6.1 (VDD), LED7.1 (VDD), LED8.1 (VDD), LED9.2 (VDD), LED10.2 (VDD), LED11.2 (VDD), U$14.1 (VIN), U$23.5 (+5V), WS2812.1; also elsewhere on the board



Board: 2 copper layers, 100.0 x 100.0 mm, 186 parts (58 on the bottom side), 118 nets.

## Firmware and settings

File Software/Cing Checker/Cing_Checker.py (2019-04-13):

#!/usr/bin/python3

import ReadCingSensors
import threading
import time
import logging
from flask import Flask
from flask import abort, redirect, url_for, jsonify
from flask import render_template
from flask import send_from_directory

temp_sensor = "Reading Value"
shine_sensor1 = "Reading Value"
shine_sensor2 = "Reading Value"
button = "Reading Value"
gyro = "Reading Value"
accelerometer = "Reading Value"
battery = "Reading Value"
sound_system = "Reading Value"
light1 = "Reading Value"
light2 = "Reading Value"
oled = "Reading Value"
char_display = "Reading Value" #16x2 display
altitude = "Reading Value" #bmp180
baro = "Reading Value" #bmp180
lidar = "Reading Value" #vl53l0x
pot = "Reading Value"
Servo = "Reading Value"
ENCA = "Reading Value"
ENCB = "Reading Value"
ultra = "Reading Value"

log = logging.getLogger('werkzeug')
log.setLevel(logging.ERROR)

app = Flask(__name__, static_url_path = "/img", static_folder = "img")

@app.before_first_request
def activate_job():
    def run_job():
        while True:
            global temp_sensor,shine_sensor1,shine_sensor2,button,gyro,accelerometer
            global battery,sound_system,light1,light2,oled,char_display,baro,altitude
            global lidar,pot,Servo,ENCA,ENCB,ultra
            data = []
            data = ReadCingSensors.ReadSensors()
            if(data != None):

                light1 = data[0]
                light2 = data[1]
                shine_sensor1 = data[2]
                shine_sensor2 = data[3]
                gyro = data[4]
                accelerometer = data[5]
                button = data[6]
                battery = data[7]
                oled = data[8]
                char_display = data[9]
                ultra = data[10]
                lidar = data[11]
                temp_sensor = data[12]
                baro = data[13]
                altitude = data[14]
                sound_system = data[15]
                pot = data[16]
                Servo = data[17]
                ENCA = data[18]
                ENCB = data[19]
                if(temp_sensor != "Fail"):
                    temp_sensor += "°C"

                if(gyro != "Fail"):
                    gyro_val = gyro.split(" ");
                    gyro = gyro_val[0] + "° " + gyro_val[1] + "° " + gyro_val[2] + "° "

            time.sleep(0.05)

    thread = threading.Thread(target=run_job)
    thread.start()


@app.route('/')
def SensorData():
    return render_template('index.html')
@app.errorhandler(404)
def page_not_found(error):
    return render_template('index.html')


if __name__ == "__main__":
    app.run(debug)

@app.route('/_update', methods= ['GET'])
def update_values():
    return jsonify(
    temp_sensor = temp_sensor,
    shine_sensor1 = shine_sensor1,
    shine_sensor2 = shine_sensor2,
    button = button,
    gyro = gyro,
    accelerometer = accelerometer,
    battery = battery,
    sound_system = sound_system,
    ultra = ultra,
    light1 = light1,
    light2 = light2,
    char_display = char_display,
    oled = oled,
    baro = baro,
    altitude=altitude,
    pot = pot,
    lidar = lidar,
    Servo = Servo,
    ENCA = ENCA,
    ENCB = ENCB
    )

if __name__ == '__main__':
    app.run(debug=False)

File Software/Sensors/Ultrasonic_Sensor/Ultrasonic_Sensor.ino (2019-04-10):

/*
Attiny84 8mhz only
*/
#include <TinyWire.h>                        
#include <Adafruit_Sensor.h>
#include <DHT.h>
#include <DHT_U.h>
#include <NewPing.h>


uint8_t address;
uint8_t triggerdistance;
uint8_t humidity;
uint8_t temperature;
uint8_t distance;

float duration;
float soundcm;
float soundsp;
DHT dht(10, DHT11);
NewPing sonar(3, 2);
void setup(){
  pinMode(0,INPUT_PULLUP);
  pinMode(8,INPUT_PULLUP);
  pinMode(9,INPUT_PULLUP);
  pinMode(7,OUTPUT);
  
  address = get_address();
  TinyWire.begin(address);
  TinyWire.onRequest(requestEvent);
  
}
void loop()
  {
    triggerdistance = map(analogRead(A1),0,1023,10,50);
    humidity = dht.readHumidity();
    temperature = dht.readTemperature();
    if (isnan(humidity) || isnan(temperature)) {
      soundsp = 331.4 + (0.606 * temperature) + (0.0124 * humidity);
    }
    else{
      soundsp = 331.4;
    }
    soundcm = soundsp / 10000;
    duration = sonar.ping_median(3);
    distance = (duration / 2) * soundcm;
    if (distance >= 100 || distance == 0){
      distance = 200;
    }
    if(distance < triggerdistance){
      digitalWrite(7,HIGH);
    }
    else{
      digitalWrite(7,LOW);
    }
    delay(30);
  }
void requestEvent()
{
  TinyWire.send(distance);
  TinyWire.send(temperature);
  TinyWire.send(humidity);
  TinyWire.send(triggerdistance);
}
uint8_t get_address(){
  uint8_t address = 16 + !digitalRead(0)*1+!digitalRead(8)*2+!digitalRead(9)*4;
  return address;
}

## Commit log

2017-05-12 Temperature sensor update
2017-05-22 Library Update
    Adding ultrasonic sensor to Library
2017-05-22 Schematic + Component Library
    Adding Schematic and Library
    [Attiny bot.sch, procesor-328p.brd, procesor-8A.brd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]
2017-05-22 Rename Attiny bot.sch to Schematic/Attiny bot.sch
    [Attiny bot.sch]
2017-05-22 Adding basic schematic
    Adding Schematic in .pdf
2017-05-22 Pictures
    Adding a pictures of schematic.
2017-05-26 Schematic of Cing
    Adding Ambient sensor
    [Attiny bot.sch]
2017-06-02 Add files via upload
    shine sensor
2017-07-18 Cing File
    Adding Sensors into schematic
    Adding better library support
    Adding 1wire ultasonic sensor
    [ShineSensor.brd, ShineSensor.sch, UltrasonicSensor.brd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]
2017-07-20 Add files via upload
    Updating Schematic
    Adding Attiny84 support
    [procesor-attiny84.brd]
2017-07-20 Schematic for Cing and procesors
    [procesor-attiny84.brd]
2017-07-24 Attiny84 Library
    Adding build it Buzzer
    Adding build it Button
    Adding build it Potentiometer
    Fixing motor bugs
2017-07-24 Attiny84 Library basic
    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
2017-07-24 Schematic of cing
    Making it look decent
    [Attiny bot.sch]
2017-07-24 Schematic of cing
    Fixing few errors such as bad position of buzzer...
    [Cing bot.sch]
2017-07-25 Schematic of Cing
    [procesor-attiny85 smd.brd]
2017-10-04 Arduino portable
2018-06-04 ESP8266 Procesor Board
    [esp8266.brd, esp8266.sch]
2018-07-22 Arduino example
2018-08-05 Deleting Schematic Folder
    [Attiny bot.brd, Attiny bot.sch, ShineSensor.brd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]
2018-08-05 Schematic files upload
    [Cing_MainBoard.brd, Cing_MainBoard.sch, Procesor-Atmega328.brd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]
2018-08-05 Adding pin 36
    [Cing_MainBoard.brd, Cing_MainBoard.sch]
2018-08-07 Adding optional 3V3 regulator
    [Cing_MainBoard.brd, Cing_MainBoard.sch]
2018-08-07 Organising folders
    [Cing_MainBoard.brd, Cing_MainBoard.sch, Procesor-Atmega328.brd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]
2018-10-20 MainBoard Upgrade
    [Cing_MainBoard.brd, Cing_MainBoard.sch]
2018-10-29 upgrading board
    [Cing_MainBoard.brd, Cing_MainBoard.sch]
2018-11-28 board change
    [Cing_MainBoard.brd, Cing_MainBoard.sch]
2018-11-30 Speak modul addon
    [SpeakModule.brd, SpeakModule.sch]
2019-02-10 Board fixes
2019-02-21 Adding Sensor readout
2019-03-09 Ultrasonic sensor
    [UltrasonicSensor.brd, UltrasonicSensor.sch]
2019-03-10 Adding better P-fet
    [Cing_MainBoard.brd, Cing_MainBoard.sch]
2019-04-10 Adding UltrasonicSensor software
2019-04-11 BoardManager 3.0.0
2019-04-12 Board Manager 3.0.0
2019-05-04 gerber update
    [Procesor-Attiny84.brd, Procesor-Attiny85.brd, ShineSensor.brd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]
2019-06-15 PCB version 3.0.1
    [Cing_MainBoard.brd, Cing_MainBoard.sch]
2019-06-15 Board version 3.1
    [Cing_MainBoard.brd, Cing_MainBoard.sch]
2019-06-25 3D package upgrade
    [Cing_MainBoard.brd, Cing_MainBoard.sch, Procesor-Atmega328.brd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]
2019-06-29 Encoder motor controller
    [MotorModule.brd, MotorModule.sch]
2019-06-29 board manager 4.0.0
2019-07-12 Panel
    contains procesors sensors and stepper driver
2019-07-18 adding more protection (motor fix)
    [Cing_MainBoard.brd, Cing_MainBoard.sch]
2019-07-24 adding CH330N
    [Cing_MainBoard.brd, Cing_MainBoard.sch]
2019-08-03 config file for Cing Checker
    [config.txt]
2019-08-10 adding minor fixes
    [Cing_MainBoard.brd, Cing_MainBoard.sch]
2019-08-10 minor changes
    [Cing_MainBoard.brd]
2019-08-11 4.1 board
    [Cing_MainBoard.brd, Cing_MainBoard.sch]
2019-08-11 fixing some bugs
    [Cing_MainBoard.brd, Cing_MainBoard.sch]
2019-08-14 panel for stepper motor procesors ultrasonic and sensors
2019-09-28 small updates on Cing 4.1
    [Cing_MainBoard.brd, Cing_MainBoard.sch]
2020-01-18 microbit procesor
    [Procesor-MicroBit.brd, Procesor-MicroBit.sch]
2020-01-22 microBit board
    [Procesor-MicroBit.brd]

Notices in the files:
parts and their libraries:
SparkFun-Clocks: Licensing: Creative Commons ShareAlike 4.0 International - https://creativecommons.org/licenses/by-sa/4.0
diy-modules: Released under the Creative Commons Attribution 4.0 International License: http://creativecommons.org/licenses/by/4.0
